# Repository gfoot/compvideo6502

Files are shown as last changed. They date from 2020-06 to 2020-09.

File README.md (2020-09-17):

# Composite/component video controller for homebrew 6502 computers

<table>
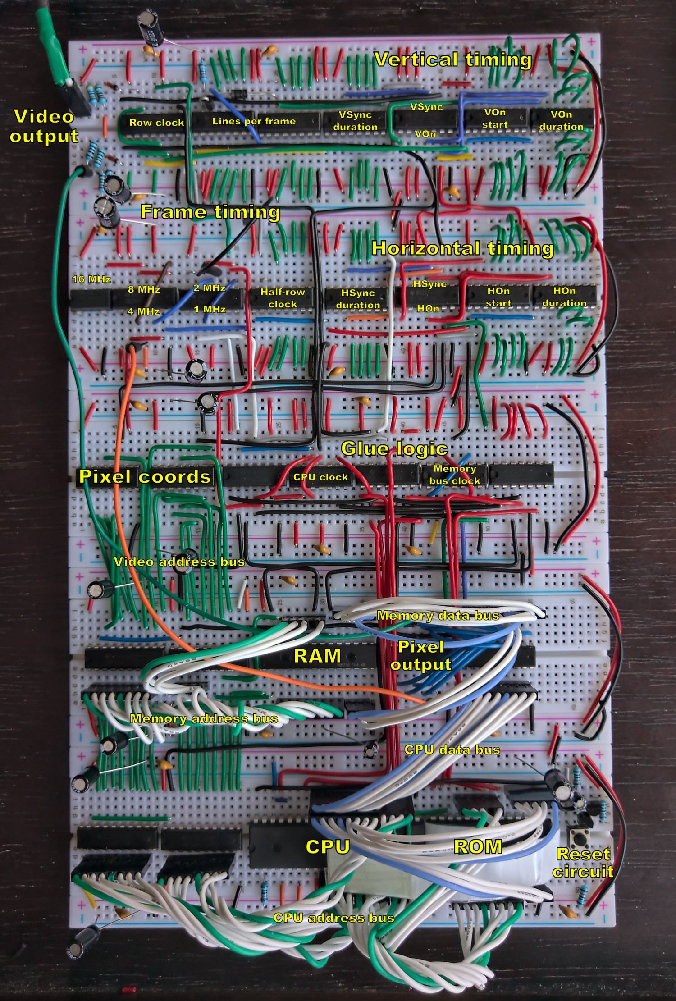
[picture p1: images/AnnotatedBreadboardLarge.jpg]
Annotated image of working build
  <tr><td rowspan="2"></td><td>Output image</td></tr>
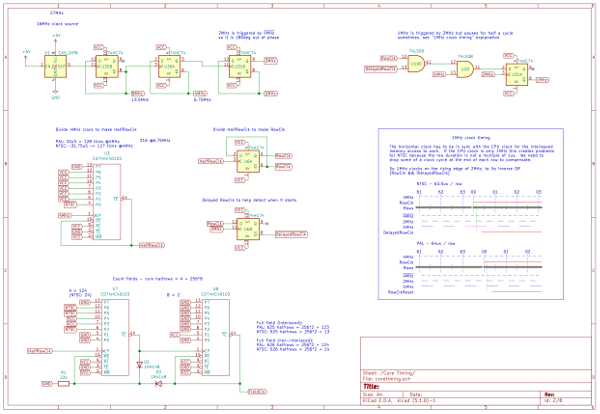
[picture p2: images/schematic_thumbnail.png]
Schematic (PDF)
  <tr><td></td></tr>
</table>

This is my second iteration video output circuit for homebrew 6502 computers.  It's designed to work in a way that's fairly close to
how early 80s microcomputers tended to work, which means RAM shared between CPU and video controller, as this tends to provide the
fastest possible access for the CPU to the video memory.

In this second iteration, the main change from V1 is that the timings are easily configurable, allowing it to support NTSC as well
as PAL with just a few jumper changes, as well as non-standard sync timings if you want to experiment; and the image placement and
size is also easily configurable.

You can also use interlacing to double the vertical resolution to 512 pixels, and if you swap the clock crystal and adjust some
other timings, you can double the horizontal resolution as well.

More involved, higher clock frequencies and maybe more counters would also allow HD resolutions such as 720p and 1080i, though I
haven't tried those yet, and VGA if you also change the output layer to output plain RGB.

The limiting factor at these higher resolutions becomes memory - 384x256x2 already uses nearly half of the RAM.  I'm considering
addressing this through a banking scheme in an upcoming V3.

# Project contents

This project contains:
* Full KiCad schematics for the new design (<a href="images/compvideo6502_schematic.pdf">also available in PDF format</a>)
* A "PCB" layout that represents how you could build this on an array of five breadboards

This includes the 6502, RAM, ROM, oscillator, reset circuit, and address decoding circuits, along 
with the video controller.  If you're already happy with the way you're doing those in an existing system then you could mostly 
keep your old design instead, but the RAM and clock need to be integrated here, in order to be shared with the video controller.

# Next steps and expansion ideas

There are a few things I plan to do next, and I'm not sure what the order will be.  Feedback/contributions welcome - let me know 
if you try these or have other ideas!

* Upload some OS code - I have the code from my previous iteration which should work pretty well
* Document and explain it, maybe make a step-by-step build-and-test guide, video tutorial, or something like that
* Make some games for it!  That was the whole point really, having a video output circuit that's fast enough to support 
the kinds of game I grew up playing
* Colour output - using component video, pretty simple to add
* Higher resolutions?  Doubling the horizontal resolution is possible with the right pixel frequency (13.5MHz instead
of 16MHz) - and doubling the vertical resolution also works fine through interlacing.  Component video can also go up to 1080i I 
think, but can't find good specs on the sync frequencies for that.
* VGA output?  It's fairly similar, just higher frequency - but may be possible by swapping the crystal and adjusting the timings.  
It's why I wanted to make this more configurable than my first one.
* Planar video memory, as used on EGA and VGA graphics cards on PCs - I've always found it an interesting architecture, and it 
seems like a good way to implement colour output without needing faster memory
* Software control over the timing registers would be very neat and not very hard to do

# Caveats

The output impedance isn't exactly what it's meant to be, but it's close enough I think.

The 16MHz base frequency is what the BBC Micro used back in the day, but I think in the digital age the standard pixel sampling 
frequency for SDTV is 13.5MHz.  As a result, on an LCD display you get blurring and moire effects at 8MHz; and at 16MHz you lose 
most of the pixel detail completely.  I think with a 13.5MHz base frequency the picture would be sharper overall.

My first iteration output correct pre- and post-vsync equalization pulses, and serrations during the vsync; I left that out this 
time around as it doesn't seem to be necessary these days.  Maybe I'm missing something though.  As far as I can tell chips like 
the 6845 never supported this anyway - at least it's not mentioned in the datasheets.  So I'm guessing that since at least the 
1980s nobody has bothered with them.

I haven't worked out interlacing yet.  Websites say that you can turn it off with the right combination of sync pulses, but my TV
always says it's interlaced, so either I'm doing it wrong, or the TV just never says "576p" anyway.  The design here is
intentionally fully-interlaced, which might lead to increased vertical resolution in the end.  It should be possible to uninterlace
it with a small change to the sync timings.  Actually I suspect that this is becase composite doesn't support progressive scan -
with component video the non-interlaced mode might work better.

I used a lot of 74HCT40103s in this design - they're incredibly useful, and were fundamental to the simplification and tweakability 
of the timings in this design.  However it seems they might be harder to find online than other chips I tend to use - I had to 
order a second batch, and it was harder to find them this time around.  So maybe it wasn't the best choice...  It's possible to use 
74HCT163s instead, but you'll need more of them as they're only 4-bit counters.

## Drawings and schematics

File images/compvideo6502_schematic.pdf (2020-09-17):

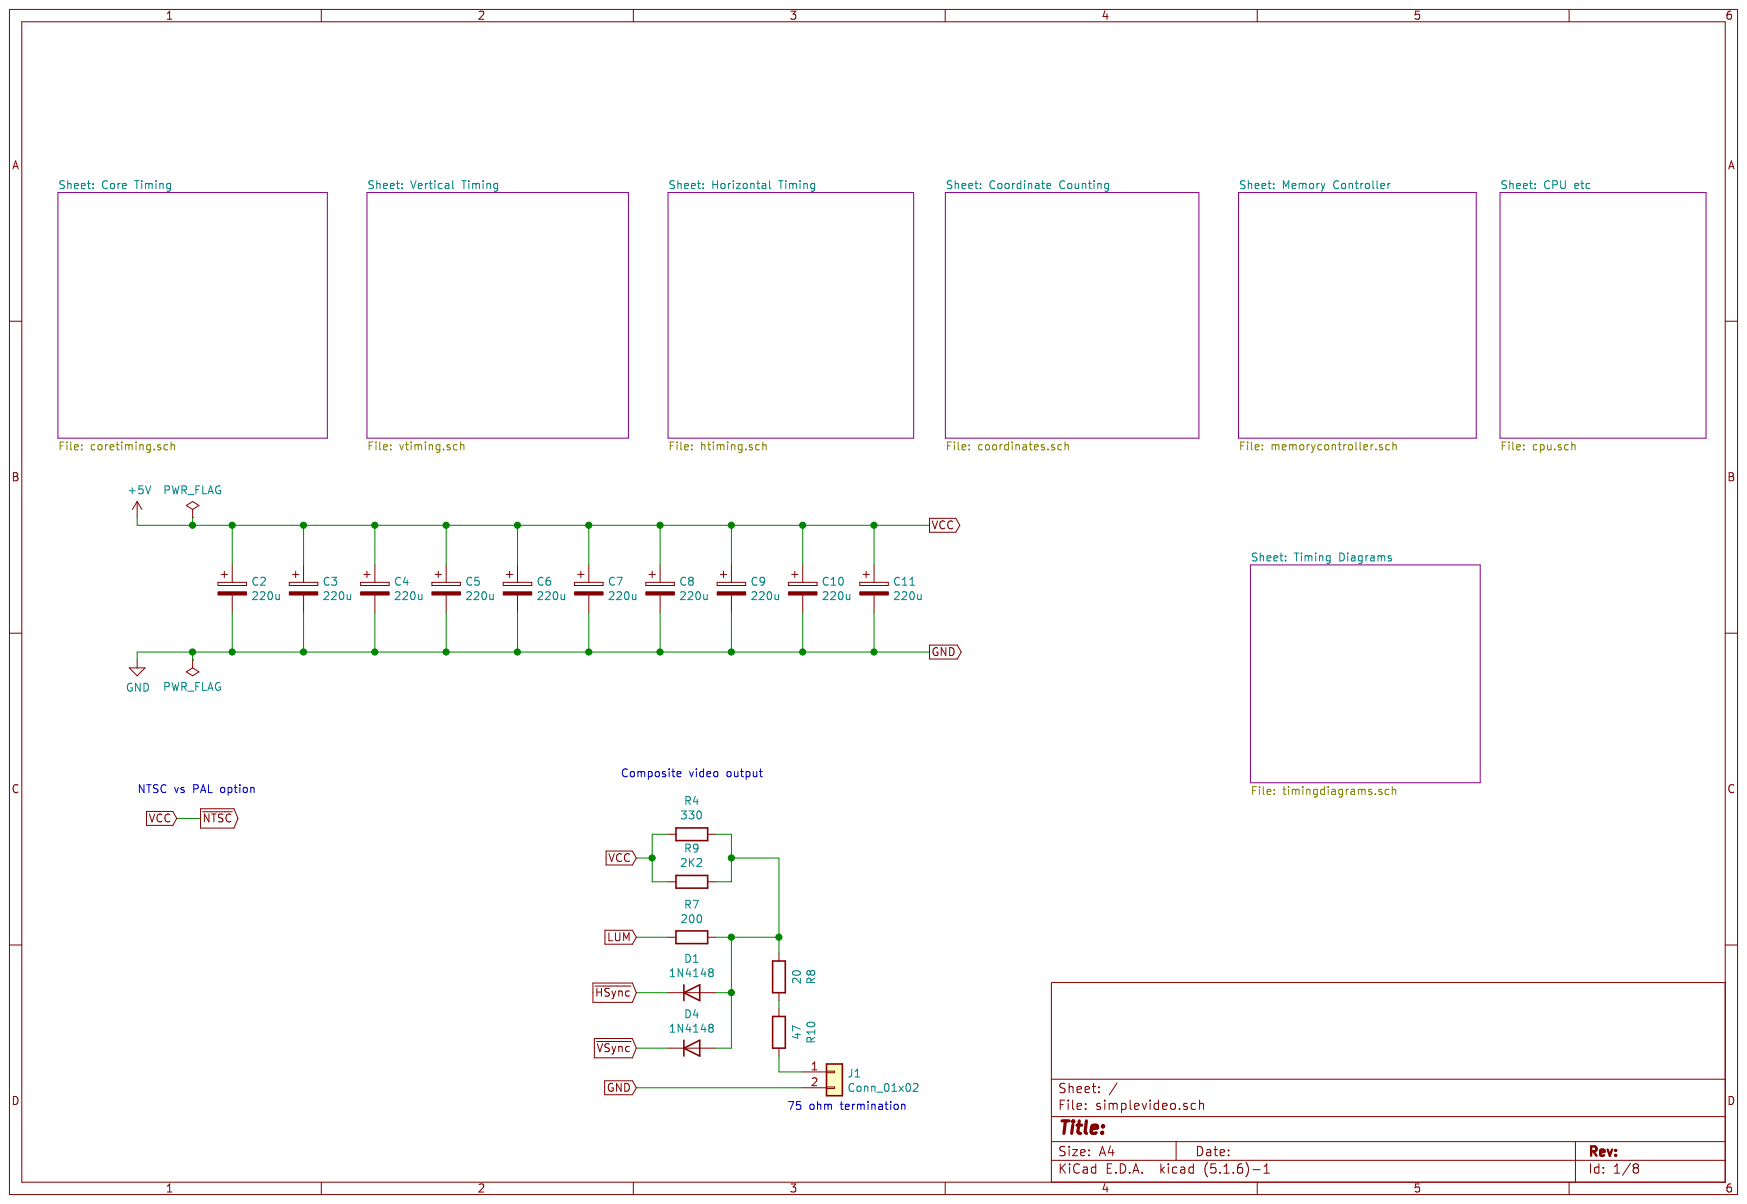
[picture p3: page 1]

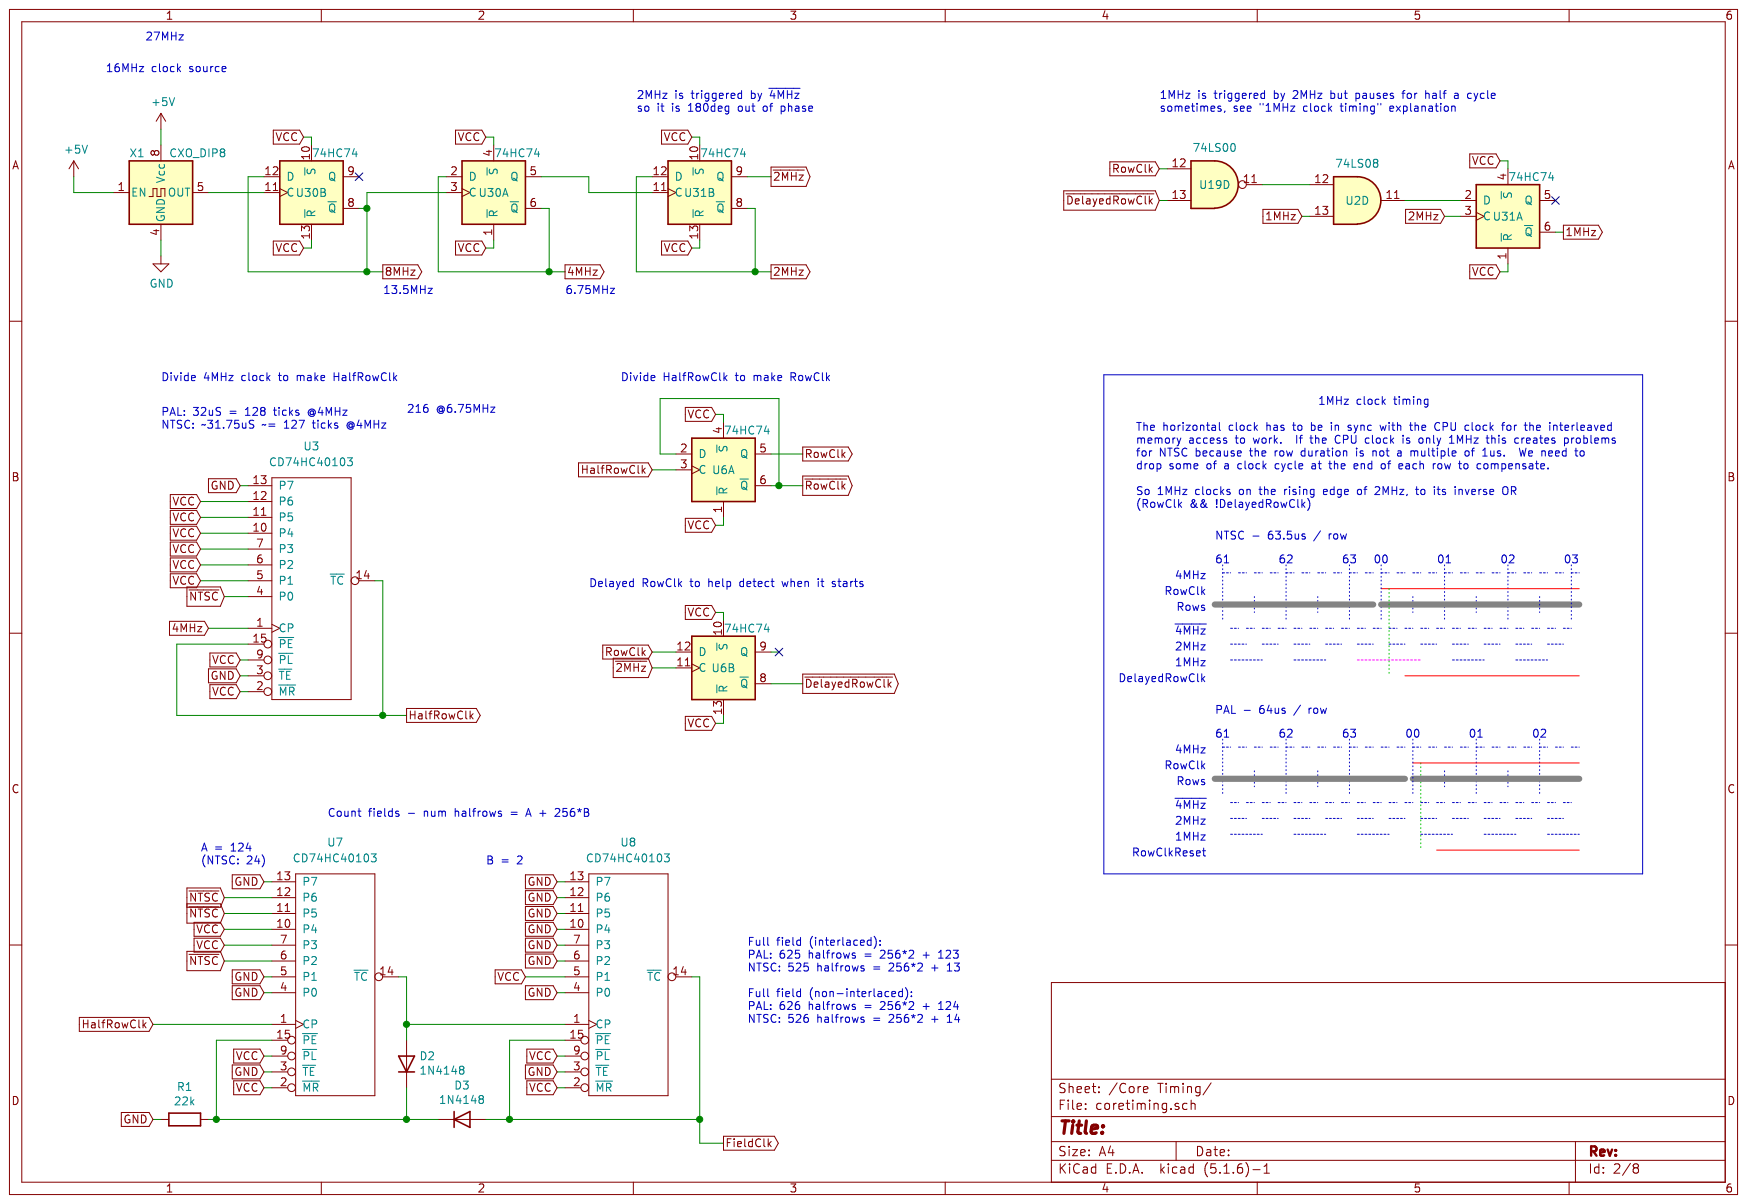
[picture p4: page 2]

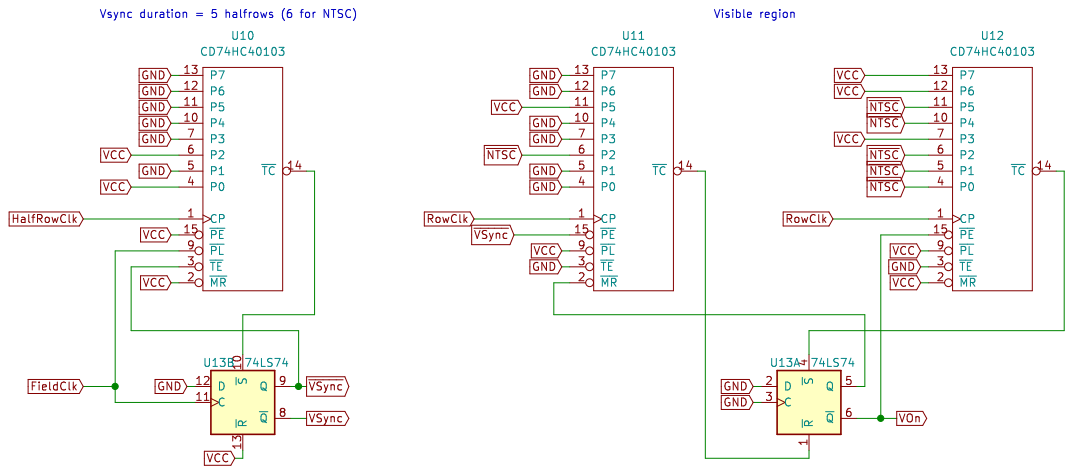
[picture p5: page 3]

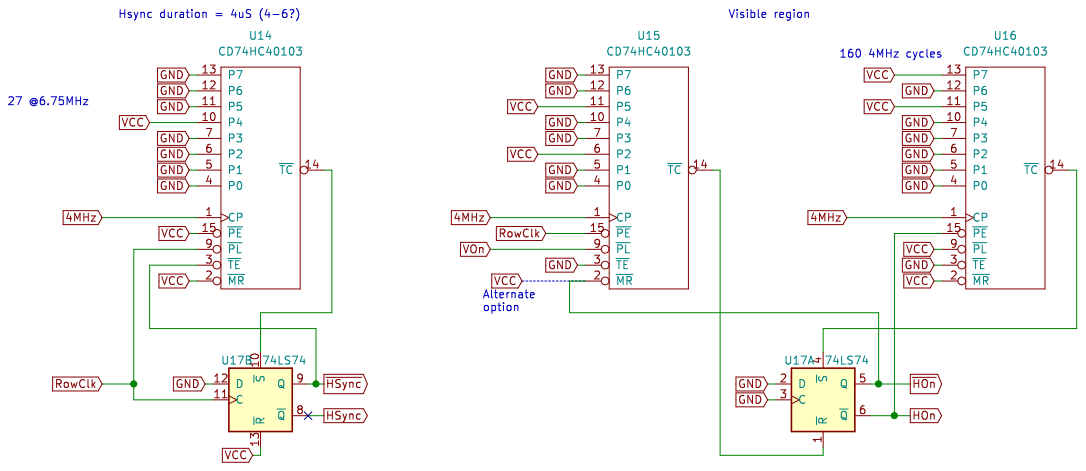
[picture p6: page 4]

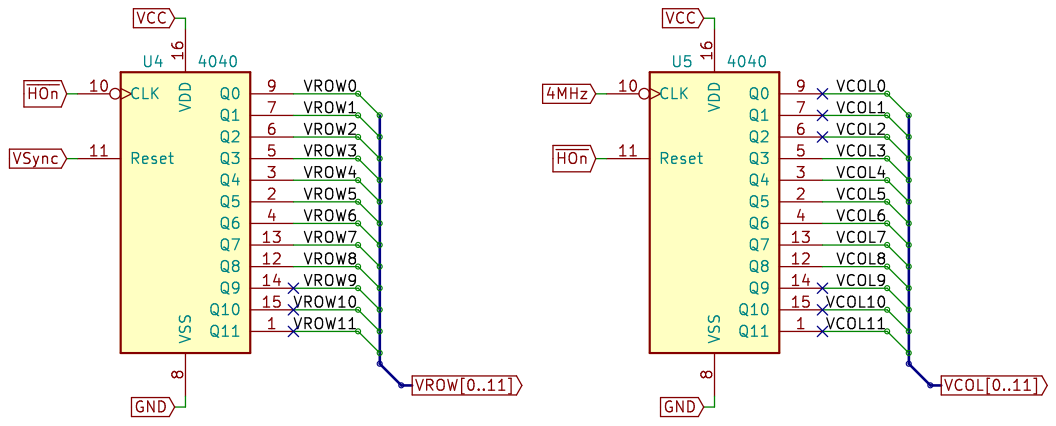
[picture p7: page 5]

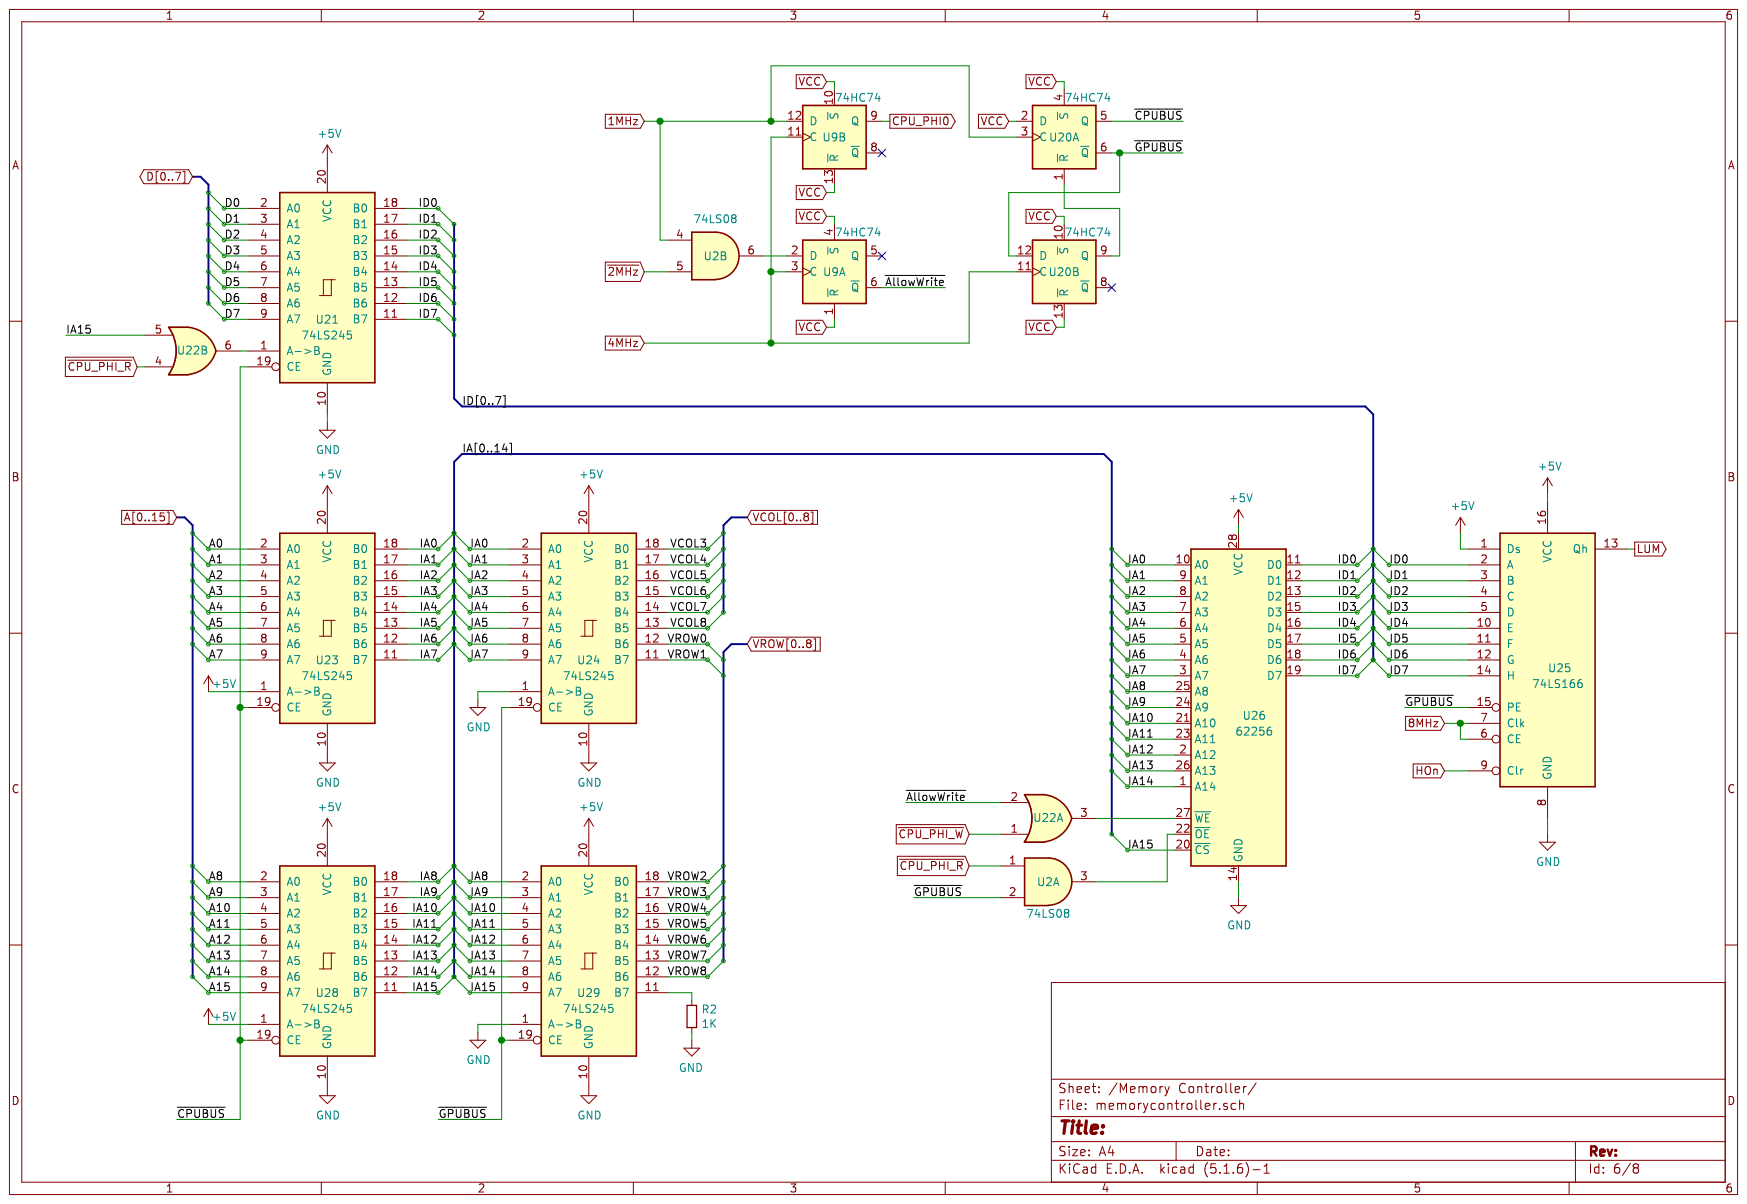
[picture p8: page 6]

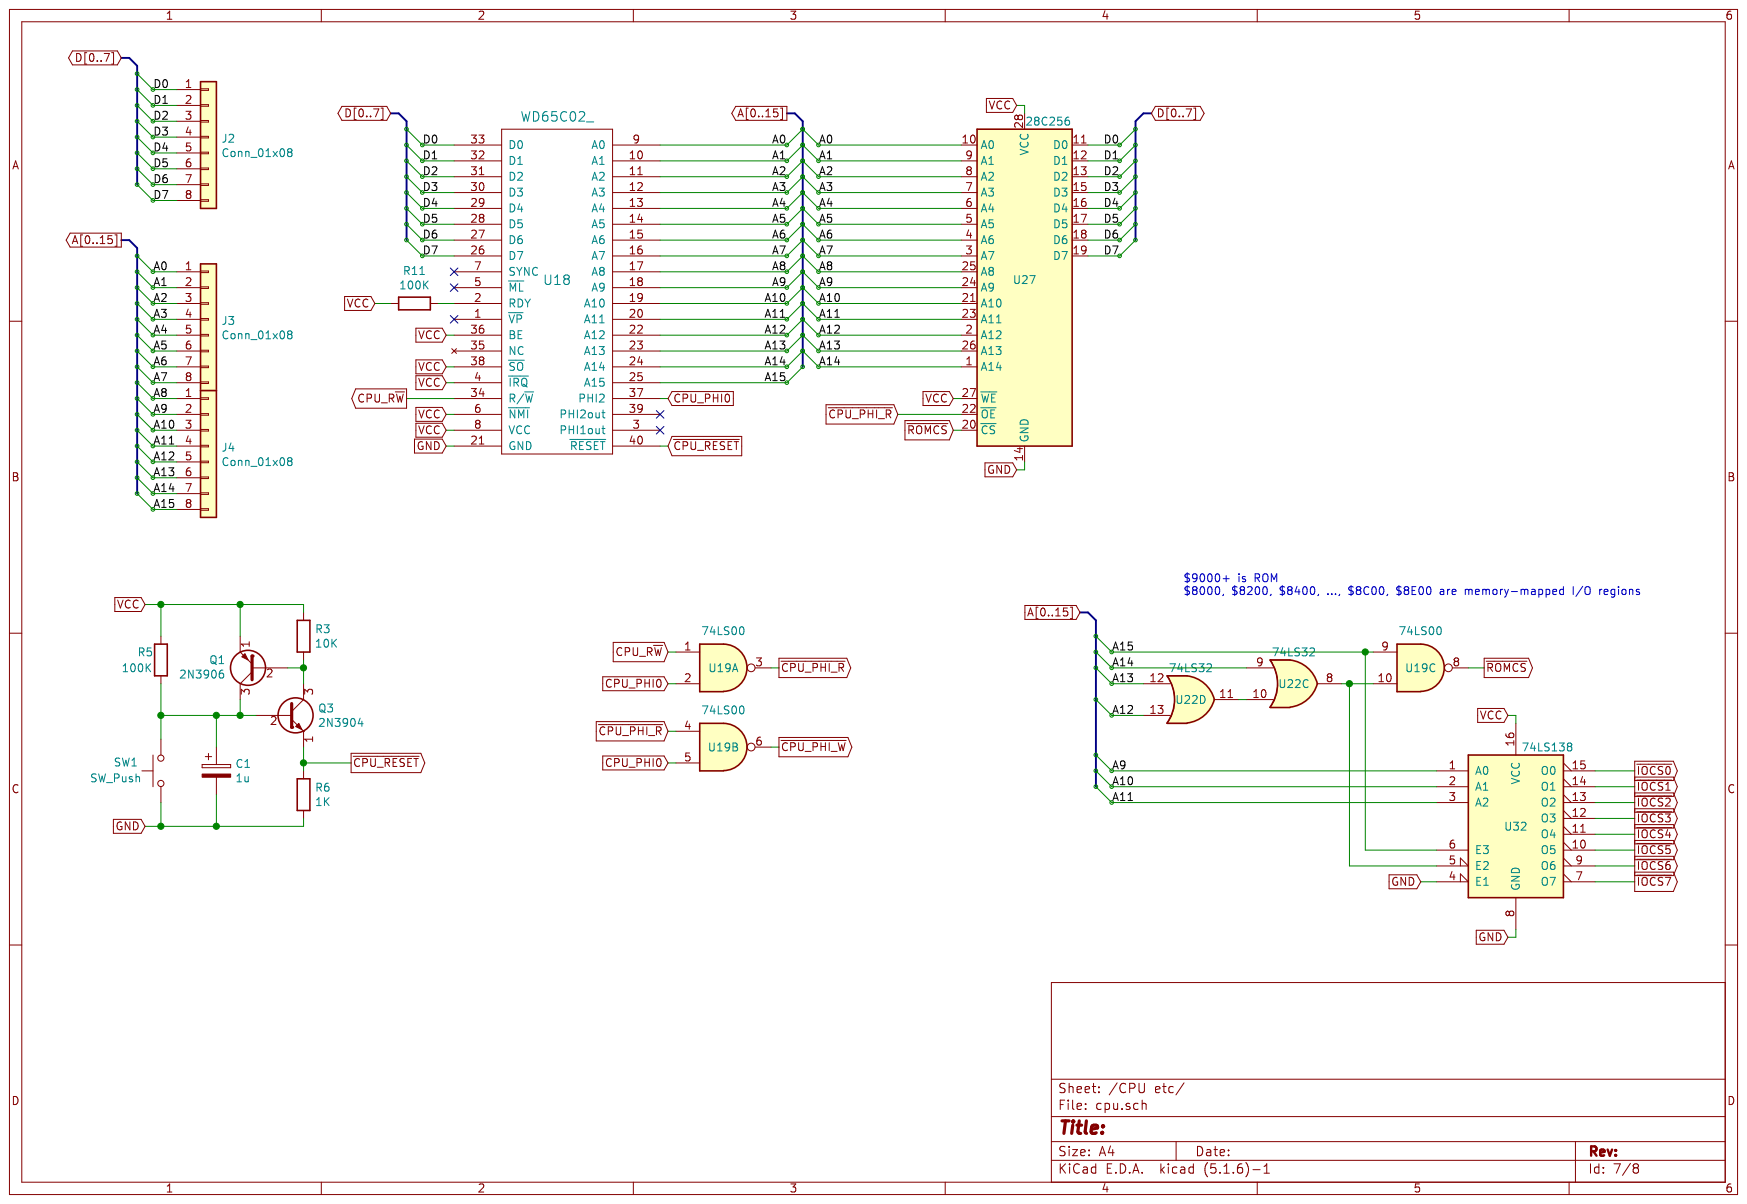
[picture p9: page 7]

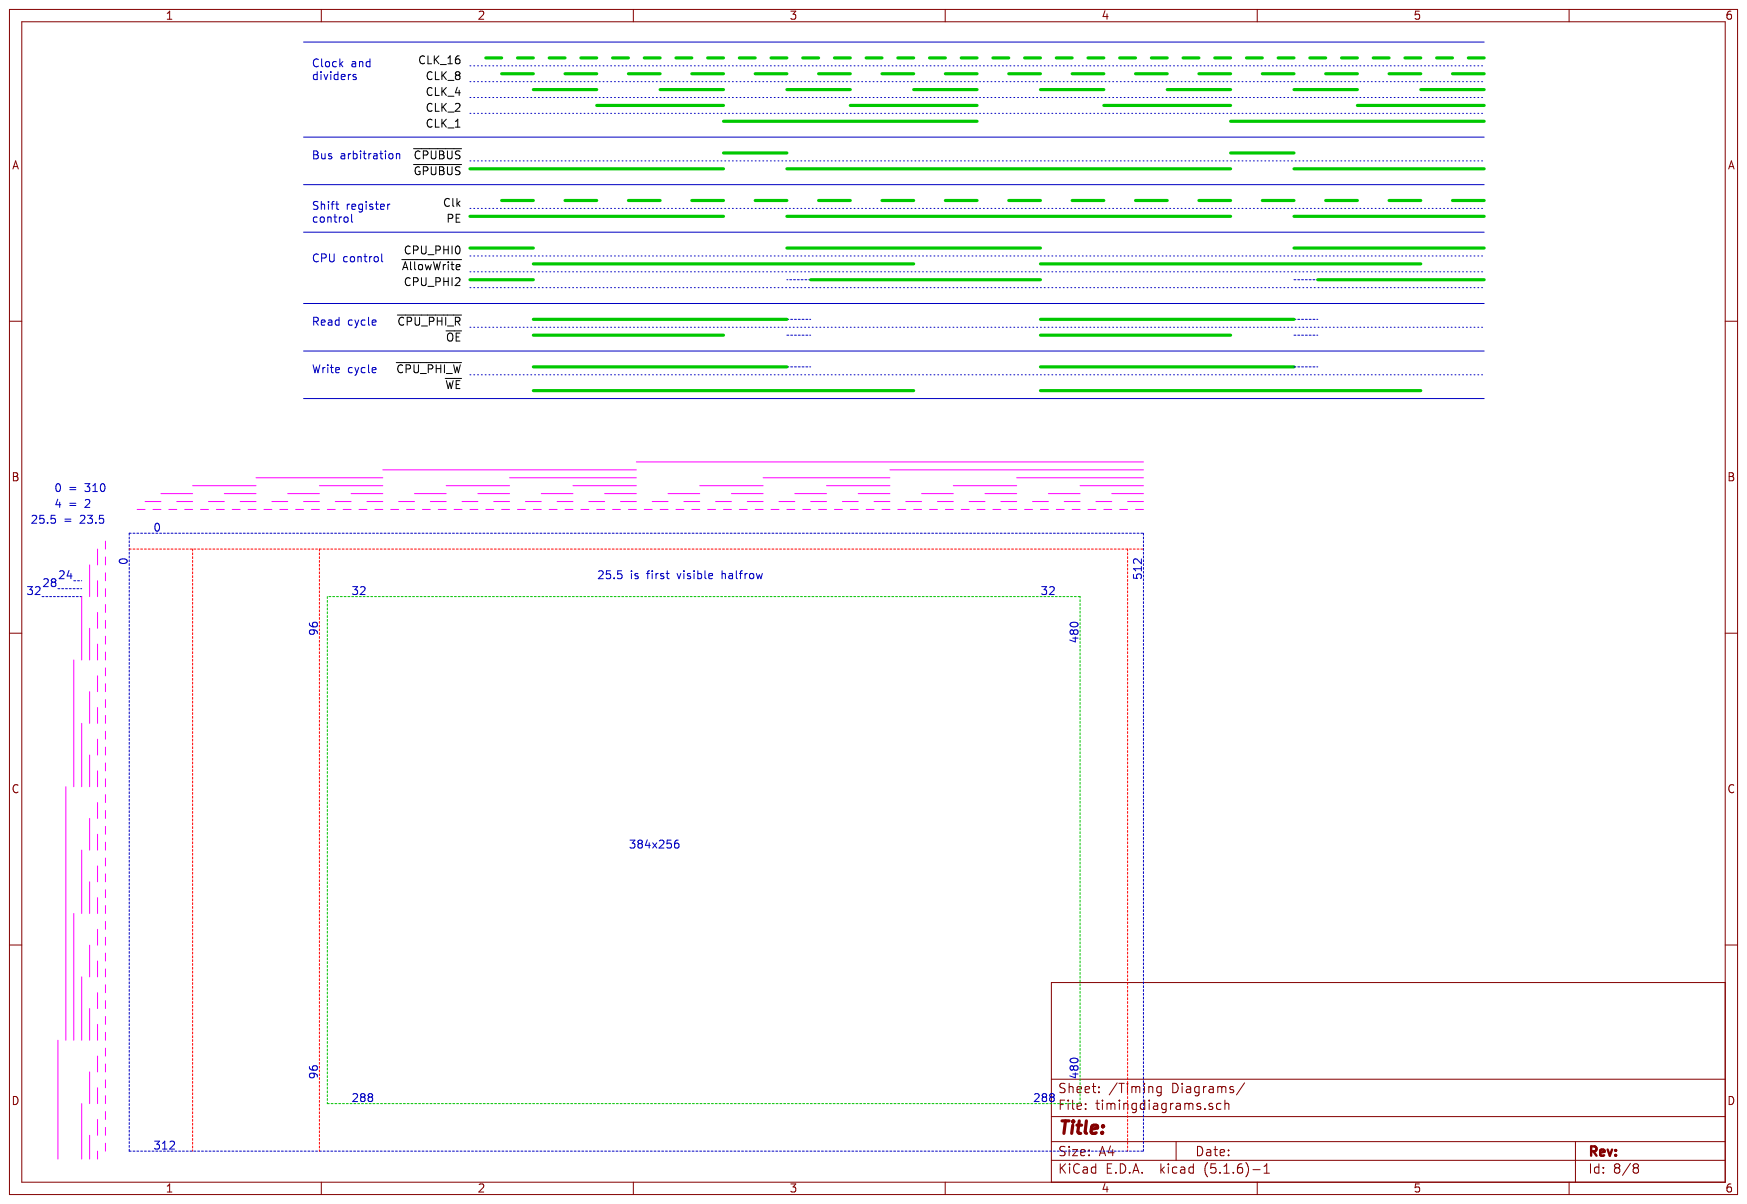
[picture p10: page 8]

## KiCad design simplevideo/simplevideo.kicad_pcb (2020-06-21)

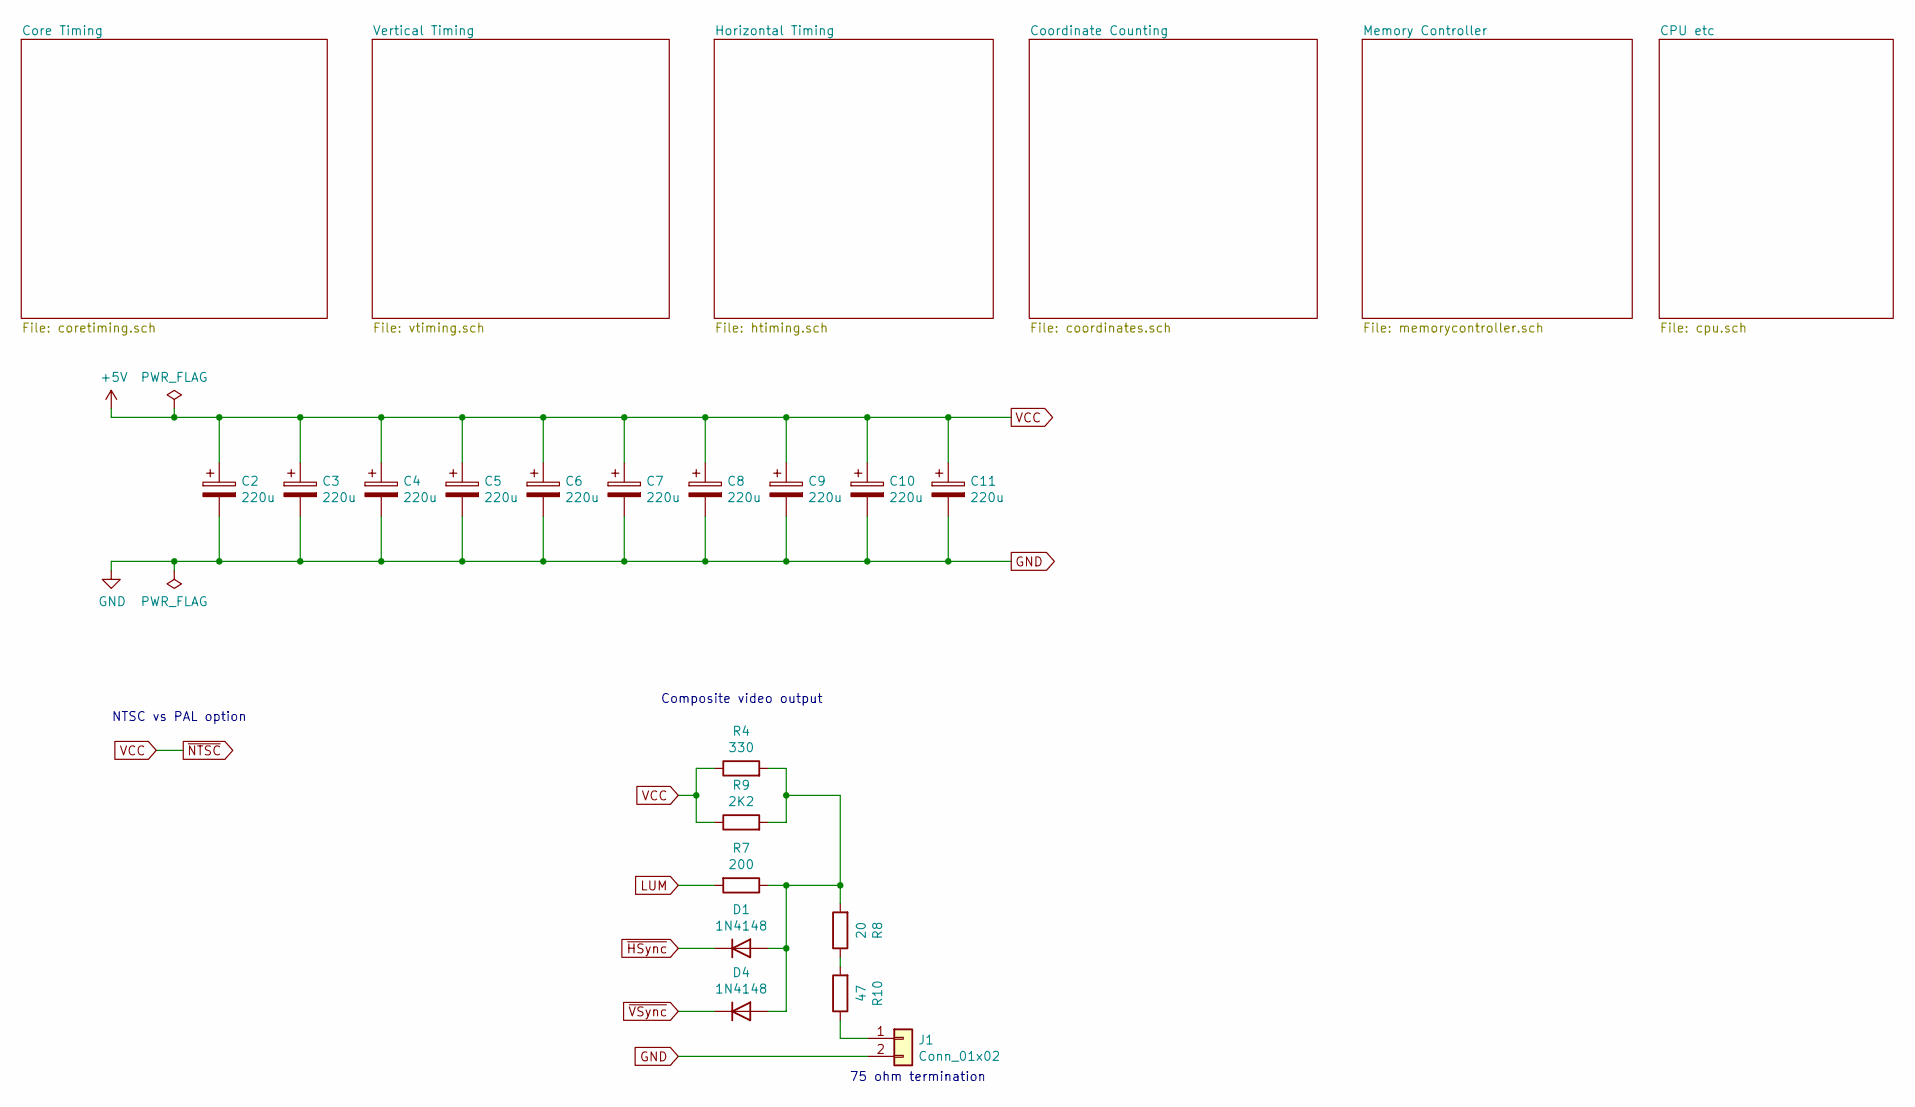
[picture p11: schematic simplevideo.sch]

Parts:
C2, C3, C4, C5, C6, C7, C8, C9, C10, C11: 220u; CP_Radial_D5.0mm_P2.50mm
D1, D4: 1N4148; D_DO-34_SOD68_P7.62mm_Horizontal
J1: Conn_01x02; PinHeader_1x02_P2.54mm_Vertical
R4: 330; R_Axial_DIN0204_L3.6mm_D1.6mm_P7.62mm_Horizontal
R7: 200; R_Axial_DIN0204_L3.6mm_D1.6mm_P7.62mm_Horizontal
R8: 20; R_Axial_DIN0204_L3.6mm_D1.6mm_P7.62mm_Horizontal
R9: 2K2; R_Axial_DIN0204_L3.6mm_D1.6mm_P7.62mm_Horizontal
R10: 47; R_Axial_DIN0204_L3.6mm_D1.6mm_P7.62mm_Horizontal

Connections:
GND: C2.2, C3.2, C4.2, C5.2, C6.2, C7.2, C8.2, C9.2, C10.2, C11.2, J1.2; also elsewhere on the board
LUM: R7.2; also elsewhere on the board
unnamed: D1.2 (A), D4.2 (A), R4.2, R7.1, R8.2, R9.2
unnamed: J1.1, R10.1
unnamed: R8.1, R10.2
VCC: C2.1, C3.1, C4.1, C5.1, C6.1, C7.1, C8.1, C9.1, C10.1, C11.1, R4.1, R9.1; also elsewhere on the board
~HSync: D1.1 (K); also elsewhere on the board
~VSync: D4.1 (K); also elsewhere on the board

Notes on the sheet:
NTSC vs PAL option
Composite video output
75 ohm termination

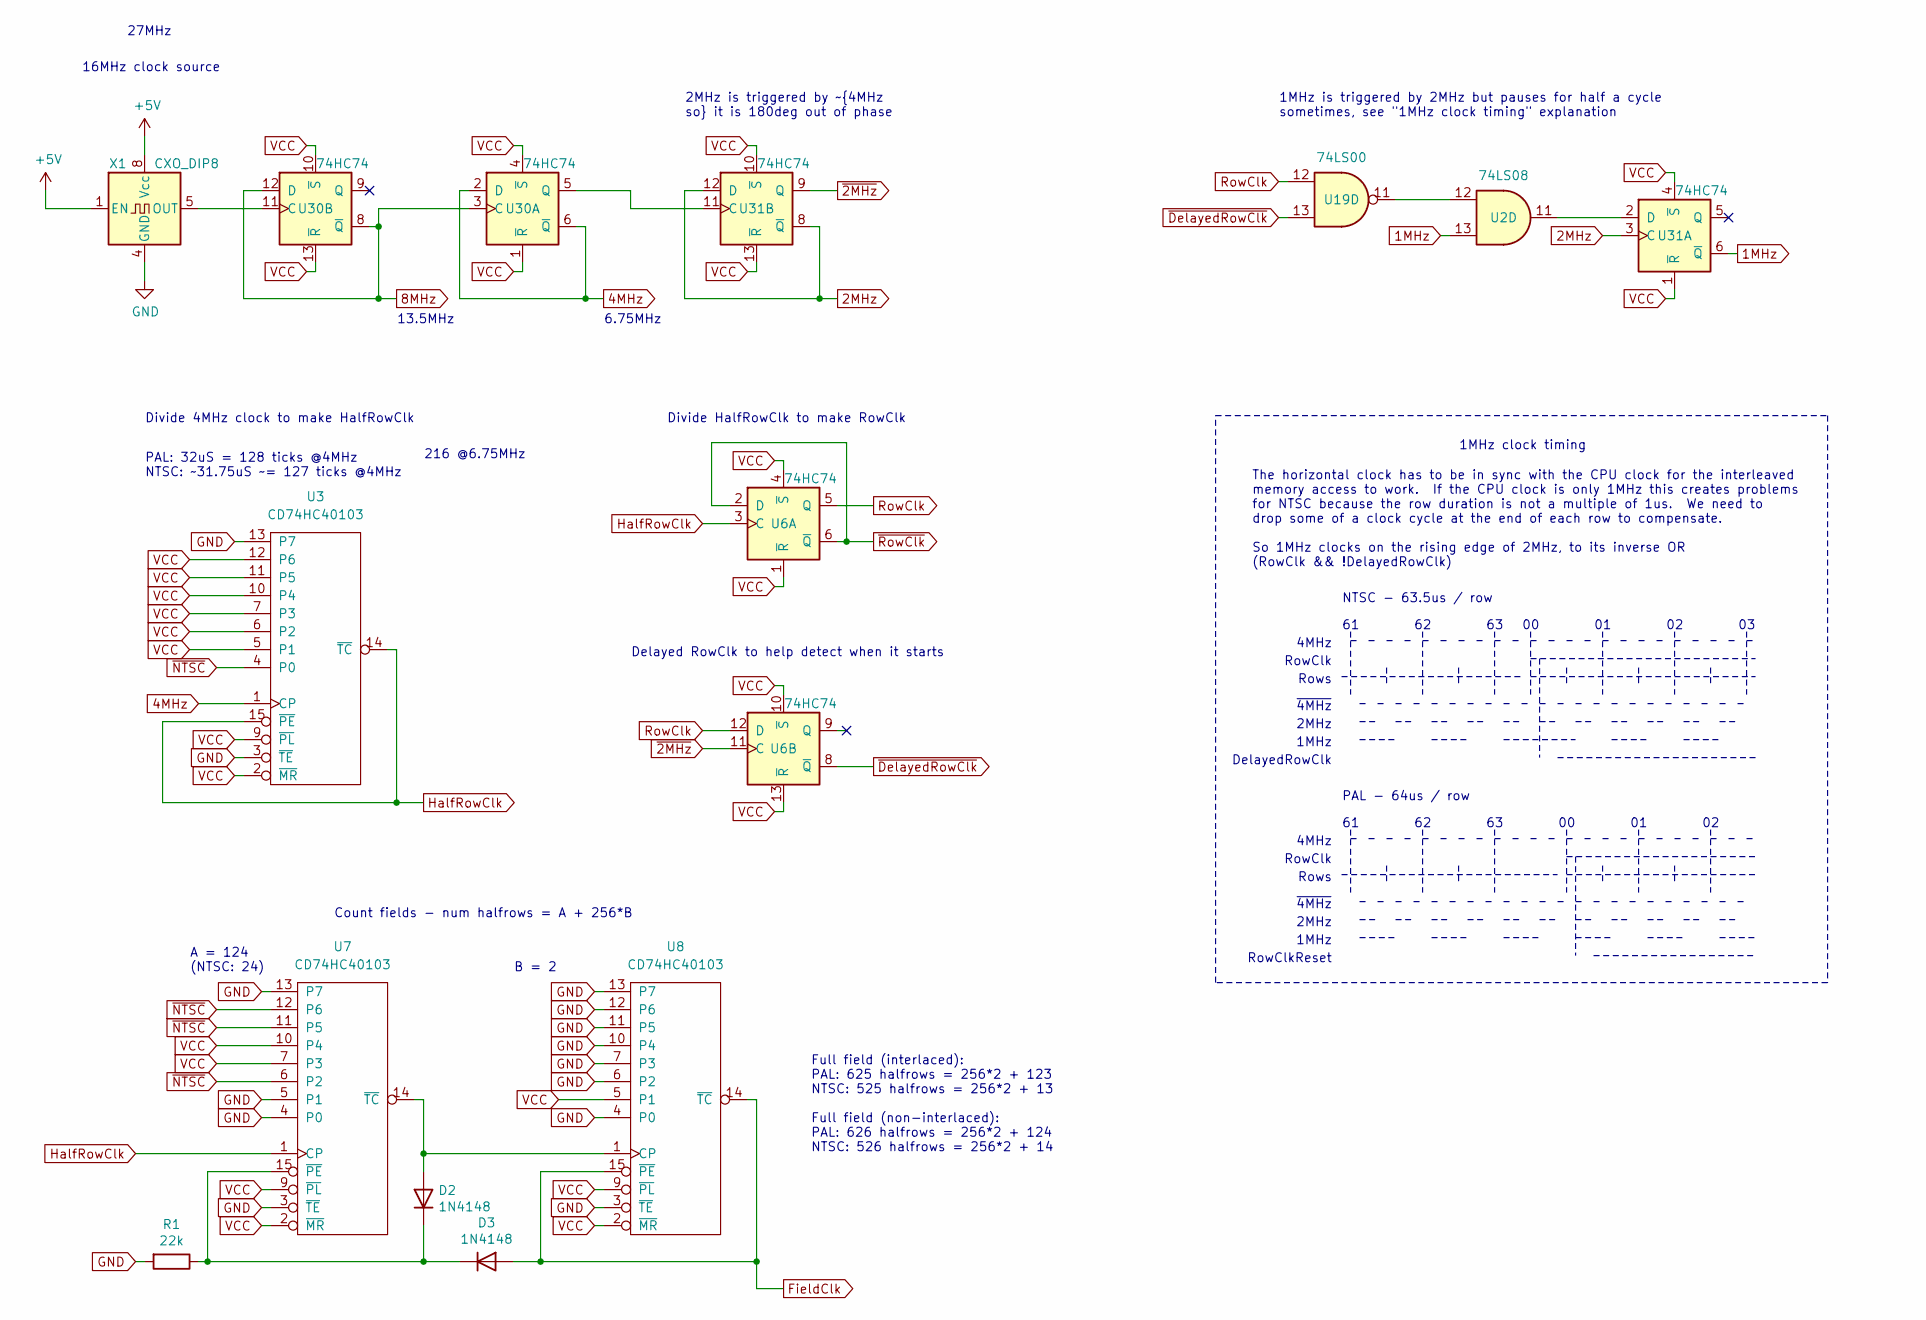
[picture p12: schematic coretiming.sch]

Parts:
D2, D3: 1N4148; D_DO-34_SOD68_P7.62mm_Horizontal
R1: 22k; R_Axial_DIN0204_L3.6mm_D1.6mm_P7.62mm_Horizontal
U2: 74LS08; DIP-14_W7.62mm
U3, U7, U8: CD74HC40103; DIP-16_W7.62mm
U6, U30, U31: 74HC74; DIP-14_W7.62mm
U19: 74LS00; DIP-14_W7.62mm
X1: CXO_DIP8; Oscillator_DIP-8

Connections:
1MHz: U2.13, U31.6 (~Q); also elsewhere on the board
2MHz: U31.3 (C), U31.8 (~Q), U31.12 (D)
4MHz: U3.1 (CP), U30.2 (D), U30.6 (~Q); also elsewhere on the board
8MHz: U30.3 (C), U30.8 (~Q), U30.12 (D); also elsewhere on the board
FieldClk: D3.2 (A), U8.14 (~TC), U8.15 (~PE); also elsewhere on the board
GND: R1.2, U3.3 (~TE), U3.8 (GND), U3.13 (P7), U7.3 (~TE), U7.4 (P0), U7.5 (P1), U7.8 (GND), U7.13 (P7), U8.3 (~TE), U8.4 (P0), U8.6 (P2), U8.7 (P3), U8.8 (GND), U8.10 (P4), U8.11 (P5), U8.12 (P6), U8.13 (P7), X1.4 (GND); also elsewhere on the board
HalfRowClk: U3.14 (~TC), U3.15 (~PE), U6.3 (C), U7.1 (CP); also elsewhere on the board
unnamed: D2.1 (K), D3.1 (K), R1.1, U7.15 (~PE)
unnamed: D2.2 (A), U7.14 (~TC), U8.1 (CP)
unnamed: U2.11, U31.2 (D)
unnamed: U2.12, U19.11
unnamed: U30.5 (Q), U31.11 (C)
unnamed: U30.11 (C), X1.5 (OUT)
RowClk: U6.5 (Q), U6.12 (D), U19.12; also elsewhere on the board
VCC: U3.2 (~MR), U3.4 (P0), U3.5 (P1), U3.6 (P2), U3.7 (P3), U3.9 (~PL), U3.10 (P4), U3.11 (P5), U3.12 (P6), U3.16 (VCC), U6.1 (~R), U6.4 (~S), U6.10 (~S), U6.13 (~R), U7.2 (~MR), U7.6 (P2), U7.7 (P3), U7.9 (~PL), U7.10 (P4), U7.11 (P5), U7.12 (P6), U7.16 (VCC), U8.2 (~MR), U8.5 (P1), U8.9 (~PL), U8.16 (VCC), U30.1 (~R), U30.4 (~S), U30.10 (~S), U30.13 (~R), U31.1 (~R), U31.4 (~S), U31.10 (~S), U31.13 (~R), X1.1 (EN), X1.8 (Vcc); also elsewhere on the board
~2MHz: U6.11 (C), U31.9 (Q); also elsewhere on the board
~DelayedRowClk: U6.8 (~Q), U19.13
~RowClk: U6.2 (D), U6.6 (~Q)

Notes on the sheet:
PAL: 32uS = 128 ticks @4MHz NTSC: ~~31.75uS ~~= 127 ticks @4MHz
Divide 4MHz clock to make HalfRowClk
Divide HalfRowClk to make RowClk
Full field (interlaced): PAL: 625 halfrows = 256*2 + 123 NTSC: 525 halfrows = 256*2 + 13 Full field (non-interlaced): PAL: 626 halfrows = 256*2 + 124 NTSC: 526 halfrows = 256*2 + 14
16MHz clock source
Count fields - num halfrows = A + 256*B
A = 124 (NTSC: 24)
B = 2
The horizontal clock has to be in sync with the CPU clock for the interleaved memory access to work. If the CPU clock is only 1MHz this creates problems for NTSC because the row duration is not a multiple of 1us. We need to drop some of a clock cycle at the end of each row to compensate. So 1MHz cl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
1MHz
2MHz
~4MHz
Rows
RowClk
4MHz
RowClkReset
NTSC - 63.5us / row
PAL - 64us / row
DelayedRowClk
1MHz clock timing
2MHz is triggered by ~4MHz so it is 180deg out of phase
1MHz is triggered by 2MHz but pauses for half a cycle sometimes, see "1MHz clock timing" explanation
Delayed RowClk to help detect when it starts
27MHz
13.5MHz
6.75MHz
216 @6.75MHz

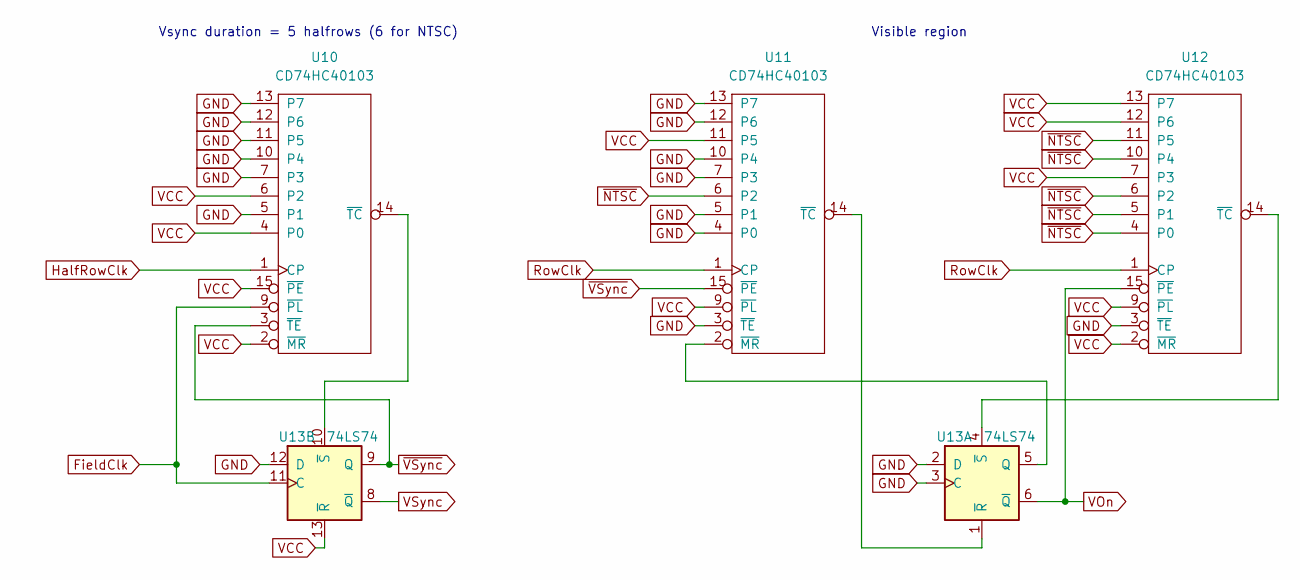
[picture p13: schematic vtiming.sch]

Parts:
U10, U11, U12: CD74HC40103; DIP-16_W7.62mm
U13: 74LS74; DIP-14_W7.62mm

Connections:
FieldClk: U10.9 (~PL), U13.11 (C); also elsewhere on the board
GND: U10.5 (P1), U10.7 (P3), U10.8 (GND), U10.10 (P4), U10.11 (P5), U10.12 (P6), U10.13 (P7), U11.3 (~TE), U11.4 (P0), U11.5 (P1), U11.7 (P3), U11.8 (GND), U11.10 (P4), U11.12 (P6), U11.13 (P7), U12.3 (~TE), U12.8 (GND), U13.2 (D), U13.3 (C), U13.12 (D); also elsewhere on the board
HalfRowClk: U10.1 (CP); also elsewhere on the board
unnamed: U10.14 (~TC), U13.10 (~S)
unnamed: U11.2 (~MR), U13.5 (Q)
unnamed: U11.14 (~TC), U13.1 (~R)
unnamed: U12.14 (~TC), U13.4 (~S)
RowClk: U11.1 (CP), U12.1 (CP); also elsewhere on the board
VCC: U10.2 (~MR), U10.4 (P0), U10.6 (P2), U10.15 (~PE), U10.16 (VCC), U11.6 (P2), U11.9 (~PL), U11.11 (P5), U11.16 (VCC), U12.2 (~MR), U12.4 (P0), U12.5 (P1), U12.6 (P2), U12.7 (P3), U12.9 (~PL), U12.10 (P4), U12.11 (P5), U12.12 (P6), U12.13 (P7), U12.16 (VCC), U13.13 (~R); also elsewhere on the board
VOn: U12.15 (~PE), U13.6 (~Q); also elsewhere on the board
VSync: U13.8 (~Q); also elsewhere on the board
~VSync: U10.3 (~TE), U11.15 (~PE), U13.9 (Q); also elsewhere on the board

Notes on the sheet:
Vsync duration = 5 halfrows (6 for NTSC)
Visible region

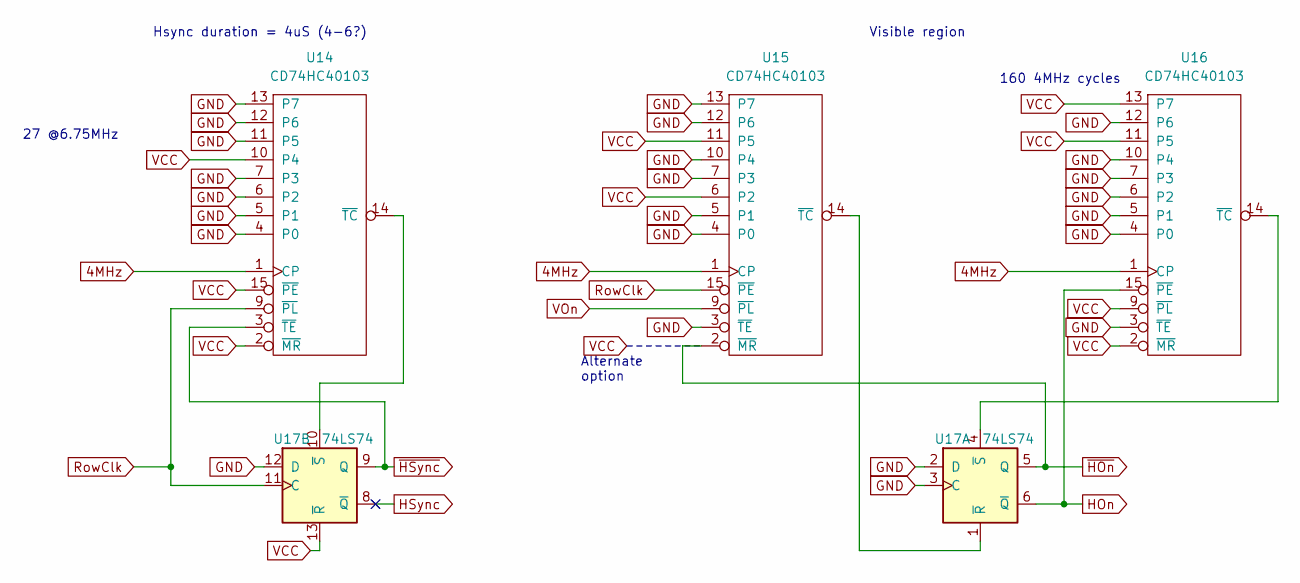
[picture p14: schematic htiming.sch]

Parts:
U14, U15, U16: CD74HC40103; DIP-16_W7.62mm
U17: 74LS74; DIP-14_W7.62mm

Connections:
4MHz: U14.1 (CP), U15.1 (CP), U16.1 (CP); also elsewhere on the board
GND: U14.4 (P0), U14.5 (P1), U14.6 (P2), U14.7 (P3), U14.8 (GND), U14.11 (P5), U14.12 (P6), U14.13 (P7), U15.3 (~TE), U15.4 (P0), U15.5 (P1), U15.7 (P3), U15.8 (GND), U15.10 (P4), U15.12 (P6), U15.13 (P7), U16.3 (~TE), U16.4 (P0), U16.5 (P1), U16.6 (P2), U16.7 (P3), U16.8 (GND), U16.10 (P4), U16.12 (P6), U17.2 (D), U17.3 (C), U17.12 (D); also elsewhere on the board
HOn: U16.15 (~PE), U17.6 (~Q); also elsewhere on the board
HSync: U17.8 (~Q)
unnamed: U14.14 (~TC), U17.10 (~S)
unnamed: U15.14 (~TC), U17.1 (~R)
unnamed: U16.14 (~TC), U17.4 (~S)
RowClk: U14.9 (~PL), U15.15 (~PE), U17.11 (C); also elsewhere on the board
VCC: U14.2 (~MR), U14.10 (P4), U14.15 (~PE), U14.16 (VCC), U15.6 (P2), U15.11 (P5), U15.16 (VCC), U16.2 (~MR), U16.9 (~PL), U16.11 (P5), U16.13 (P7), U16.16 (VCC), U17.13 (~R); also elsewhere on the board
VOn: U15.9 (~PL); also elsewhere on the board
~HOn: U15.2 (~MR), U17.5 (Q); also elsewhere on the board
~HSync: U14.3 (~TE), U17.9 (Q); also elsewhere on the board

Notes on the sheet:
Hsync duration = 4uS (4-6?)
Visible region
Alternate option
27 @6.75MHz
160 4MHz cycles

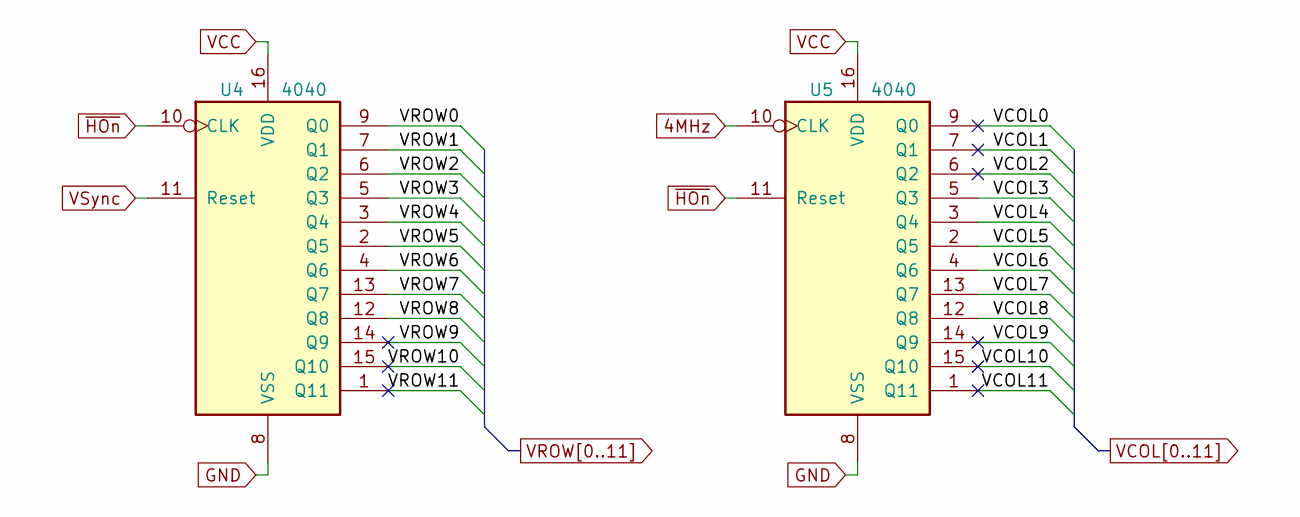
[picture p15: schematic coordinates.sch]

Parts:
U4, U5: 4040; DIP-16_W7.62mm

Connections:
4MHz: U5.10 (CLK); also elsewhere on the board
GND: U4.8 (VSS), U5.8 (VSS); also elsewhere on the board
VCC: U4.16 (VDD), U5.16 (VDD); also elsewhere on the board
VCOL0: U5.9 (Q0)
VCOL1: U5.7 (Q1)
VCOL2: U5.6 (Q2)
VCOL3: U5.5 (Q3); also elsewhere on the board
VCOL4: U5.3 (Q4); also elsewhere on the board
VCOL5: U5.2 (Q5); also elsewhere on the board
VCOL6: U5.4 (Q6); also elsewhere on the board
VCOL7: U5.13 (Q7); also elsewhere on the board
VCOL8: U5.12 (Q8); also elsewhere on the board
VCOL9: U5.14 (Q9)
VCOL10: U5.15 (Q10)
VCOL11: U5.1 (Q11)
VROW0: U4.9 (Q0); also elsewhere on the board
VROW1: U4.7 (Q1); also elsewhere on the board
VROW2: U4.6 (Q2); also elsewhere on the board
VROW3: U4.5 (Q3); also elsewhere on the board
VROW4: U4.3 (Q4); also elsewhere on the board
VROW5: U4.2 (Q5); also elsewhere on the board
VROW6: U4.4 (Q6); also elsewhere on the board
VROW7: U4.13 (Q7); also elsewhere on the board
VROW8: U4.12 (Q8); also elsewhere on the board
VROW9: U4.14 (Q9)
VROW10: U4.15 (Q10)
VROW11: U4.1 (Q11)
VSync: U4.11 (Reset); also elsewhere on the board
~HOn: U4.10 (CLK), U5.11 (Reset); also elsewhere on the board

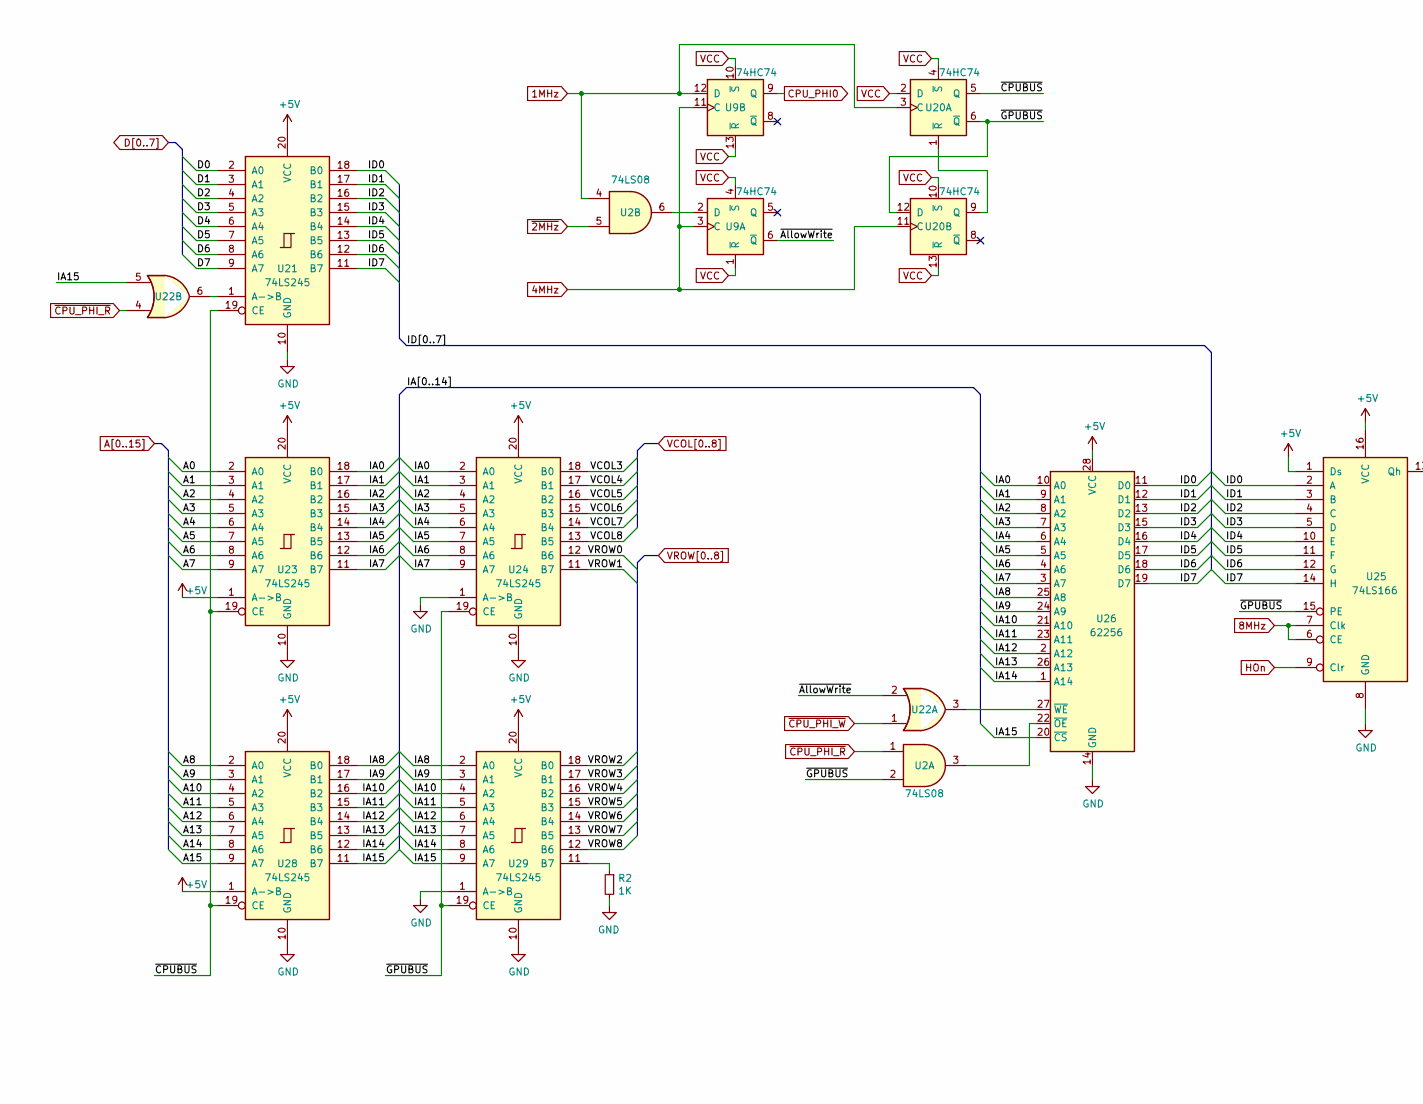
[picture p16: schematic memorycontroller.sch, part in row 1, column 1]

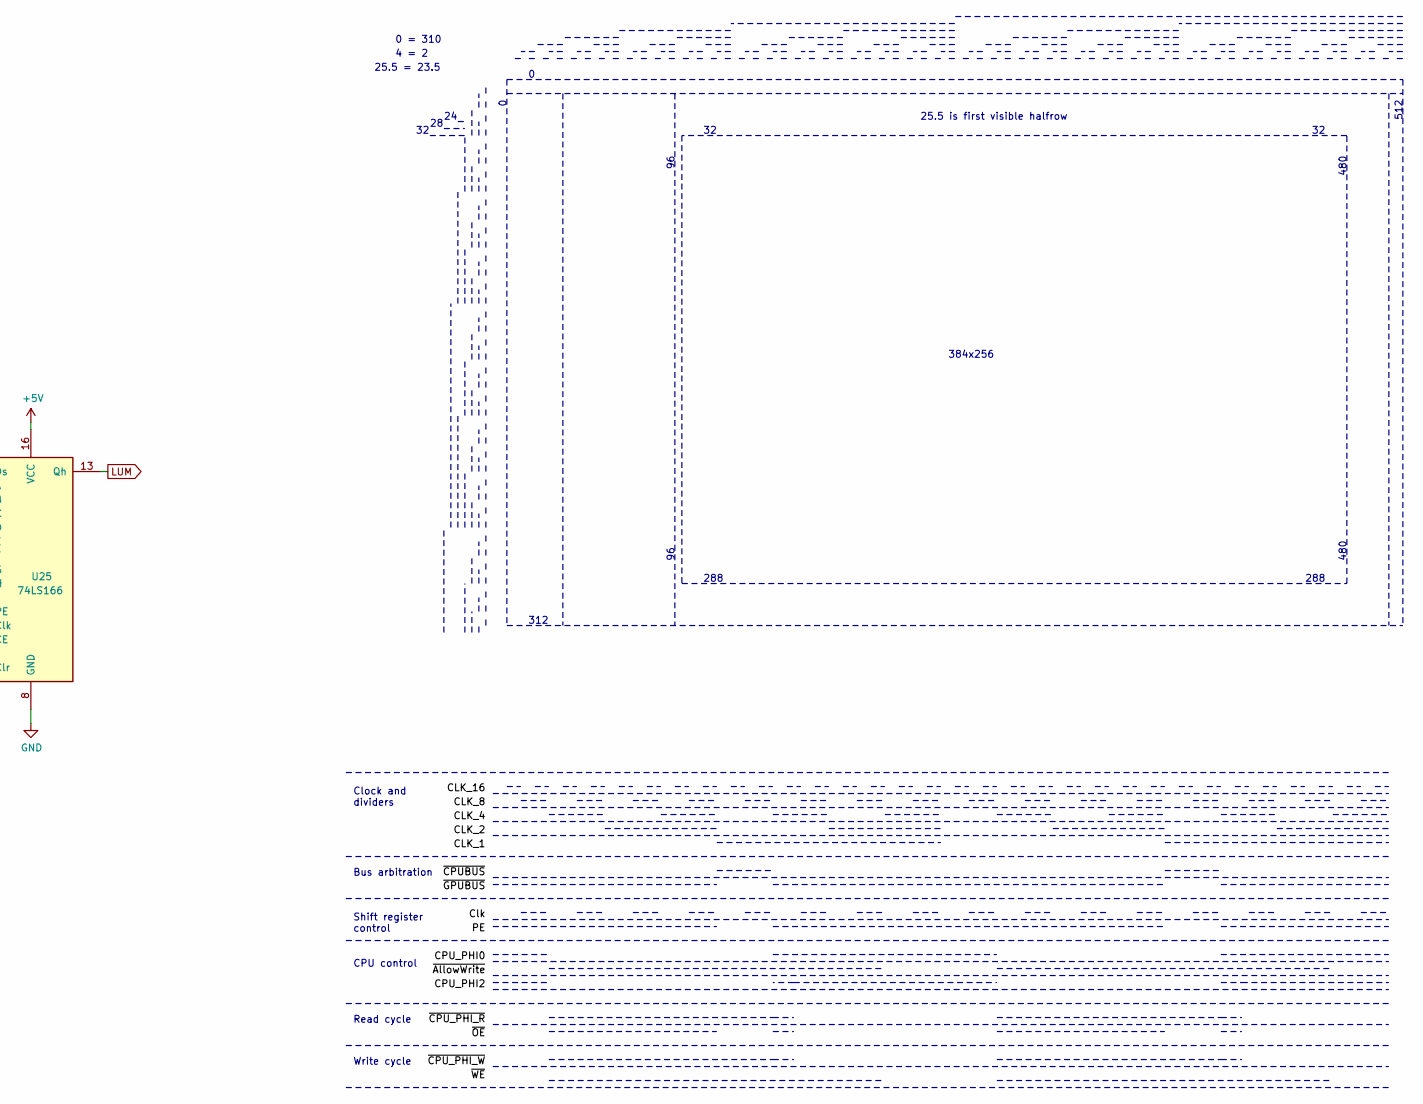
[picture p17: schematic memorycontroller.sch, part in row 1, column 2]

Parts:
R2: 1K; R_Axial_DIN0207_L6.3mm_D2.5mm_P7.62mm_Horizontal
U2: 74LS08; DIP-14_W7.62mm
U9, U20: 74HC74; DIP-14_W7.62mm
U21, U23, U24, U28, U29: 74LS245; DIP-20_W7.62mm
U22: 74LS32; DIP-14_W7.62mm
U25: 74LS166; DIP-16_W7.62mm
U26: 62256; DIP-28_W15.24mm

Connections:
1MHz: U2.4, U9.12 (D), U20.3 (C); also elsewhere on the board
4MHz: U9.3 (C), U9.11 (C), U20.11 (C); also elsewhere on the board
8MHz: U25.6 (CE), U25.7 (Clk); also elsewhere on the board
/Memory Controller/IA0: U23.18 (B0), U24.2 (A0), U26.10 (A0)
/Memory Controller/IA1: U23.17 (B1), U24.3 (A1), U26.9 (A1)
/Memory Controller/IA2: U23.16 (B2), U24.4 (A2), U26.8 (A2)
/Memory Controller/IA3: U23.15 (B3), U24.5 (A3), U26.7 (A3)
/Memory Controller/IA4: U23.14 (B4), U24.6 (A4), U26.6 (A4)
/Memory Controller/IA5: U23.13 (B5), U24.7 (A5), U26.5 (A5)
/Memory Controller/IA6: U23.12 (B6), U24.8 (A6), U26.4 (A6)
/Memory Controller/IA7: U23.11 (B7), U24.9 (A7), U26.3 (A7)
/Memory Controller/IA8: U26.25 (A8), U28.18 (B0), U29.2 (A0)
/Memory Controller/IA9: U26.24 (A9), U28.17 (B1), U29.3 (A1)
/Memory Controller/IA10: U26.21 (A10), U28.16 (B2), U29.4 (A2)
/Memory Controller/IA11: U26.23 (A11), U28.15 (B3), U29.5 (A3)
/Memory Controller/IA12: U26.2 (A12), U28.14 (B4), U29.6 (A4)
/Memory Controller/IA13: U26.26 (A13), U28.13 (B5), U29.7 (A5)
/Memory Controller/IA14: U26.1 (A14), U28.12 (B6), U29.8 (A6)
/Memory Controller/IA15: U22.5, U26.20 (~CS), U28.11 (B7), U29.9 (A7)
/Memory Controller/ID0: U21.18 (B0), U25.2 (A), U26.11 (D0)
/Memory Controller/ID1: U21.17 (B1), U25.3 (B), U26.12 (D1)
/Memory Controller/ID2: U21.16 (B2), U25.4 (C), U26.13 (D2)
/Memory Controller/ID3: U21.15 (B3), U25.5 (D), U26.15 (D3)
/Memory Controller/ID4: U21.14 (B4), U25.10 (E), U26.16 (D4)
/Memory Controller/ID5: U21.13 (B5), U25.11 (F), U26.17 (D5)
/Memory Controller/ID6: U21.12 (B6), U25.12 (G), U26.18 (D6)
/Memory Controller/ID7: U21.11 (B7), U25.14 (H), U26.19 (D7)
/Memory Controller/~AllowWrite: U9.6 (~Q), U22.2
/Memory Controller/~CPUBUS: U20.5 (Q), U21.19 (CE), U23.19 (CE), U28.19 (CE)
/Memory Controller/~GPUBUS: U2.2, U20.6 (~Q), U20.12 (D), U24.19 (CE), U25.15 (PE), U29.19 (CE)
A0: U23.2 (A0); also elsewhere on the board
A1: U23.3 (A1); also elsewhere on the board
A2: U23.4 (A2); also elsewhere on the board
A3: U23.5 (A3); also elsewhere on the board
A4: U23.6 (A4); also elsewhere on the board
A5: U23.7 (A5); also elsewhere on the board
A6: U23.8 (A6); also elsewhere on the board
A7: U23.9 (A7); also elsewhere on the board
A8: U28.2 (A0); also elsewhere on the board
A9: U28.3 (A1); also elsewhere on the board
A10: U28.4 (A2); also elsewhere on the board
A11: U28.5 (A3); also elsewhere on the board
A12: U28.6 (A4); also elsewhere on the board
A13: U28.7 (A5); also elsewhere on the board
A14: U28.8 (A6); also elsewhere on the board
A15: U28.9 (A7); also elsewhere on the board
CPU_PHI0: U9.9 (Q); also elsewhere on the board
D0: U21.2 (A0); also elsewhere on the board
D1: U21.3 (A1); also elsewhere on the board
D2: U21.4 (A2); also elsewhere on the board
D3: U21.5 (A3); also elsewhere on the board
D4: U21.6 (A4); also elsewhere on the board
D5: U21.7 (A5); also elsewhere on the board
D6: U21.8 (A6); also elsewhere on the board
D7: U21.9 (A7); also elsewhere on the board
GND: R2.2, U21.10 (GND), U23.10 (GND), U24.1 (A->B), U24.10 (GND), U25.8 (GND), U26.14 (GND), U28.10 (GND), U29.1 (A->B), U29.10 (GND); also elsewhere on the board
HOn: U25.9 (Clr); also elsewhere on the board
LUM: U25.13 (Qh); also elsewhere on the board
unnamed: R2.1, U29.11 (B7)
unnamed: U2.3, U26.22 (~OE)
unnamed: U2.6, U9.2 (D)
unnamed: U20.1 (~R), U20.9 (Q)
unnamed: U21.1 (A->B), U22.6
unnamed: U22.3, U26.27 (~WE)
VCC: U9.1 (~R), U9.4 (~S), U9.10 (~S), U9.13 (~R), U20.2 (D), U20.4 (~S), U20.10 (~S), U20.13 (~R), U21.20 (VCC), U23.1 (A->B), U23.20 (VCC), U24.20 (VCC), U25.1 (Ds), U25.16 (VCC), U26.28 (VCC), U28.1 (A->B), U28.20 (VCC), U29.20 (VCC); also elsewhere on the board
VCOL3: U24.18 (B0); also elsewhere on the board
VCOL4: U24.17 (B1); also elsewhere on the board
VCOL5: U24.16 (B2); also elsewhere on the board
VCOL6: U24.15 (B3); also elsewhere on the board
VCOL7: U24.14 (B4); also elsewhere on the board
VCOL8: U24.13 (B5); also elsewhere on the board
VROW0: U24.12 (B6); also elsewhere on the board
VROW1: U24.11 (B7); also elsewhere on the board
VROW2: U29.18 (B0); also elsewhere on the board
VROW3: U29.17 (B1); also elsewhere on the board
VROW4: U29.16 (B2); also elsewhere on the board
VROW5: U29.15 (B3); also elsewhere on the board
VROW6: U29.14 (B4); also elsewhere on the board
VROW7: U29.13 (B5); also elsewhere on the board
VROW8: U29.12 (B6); also elsewhere on the board
~2MHz: U2.5; also elsewhere on the board
~CPU_PHI_R: U2.1, U22.4; also elsewhere on the board
~CPU_PHI_W: U22.1; also elsewhere on the board

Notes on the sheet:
512
312
25.5 is first visible halfrow
0 = 310
4 = 2
25.5 = 23.5
480
288
384x256
Shift register control
CPU control
Read cycle
Write cycle
Clock and dividers
Bus arbitration

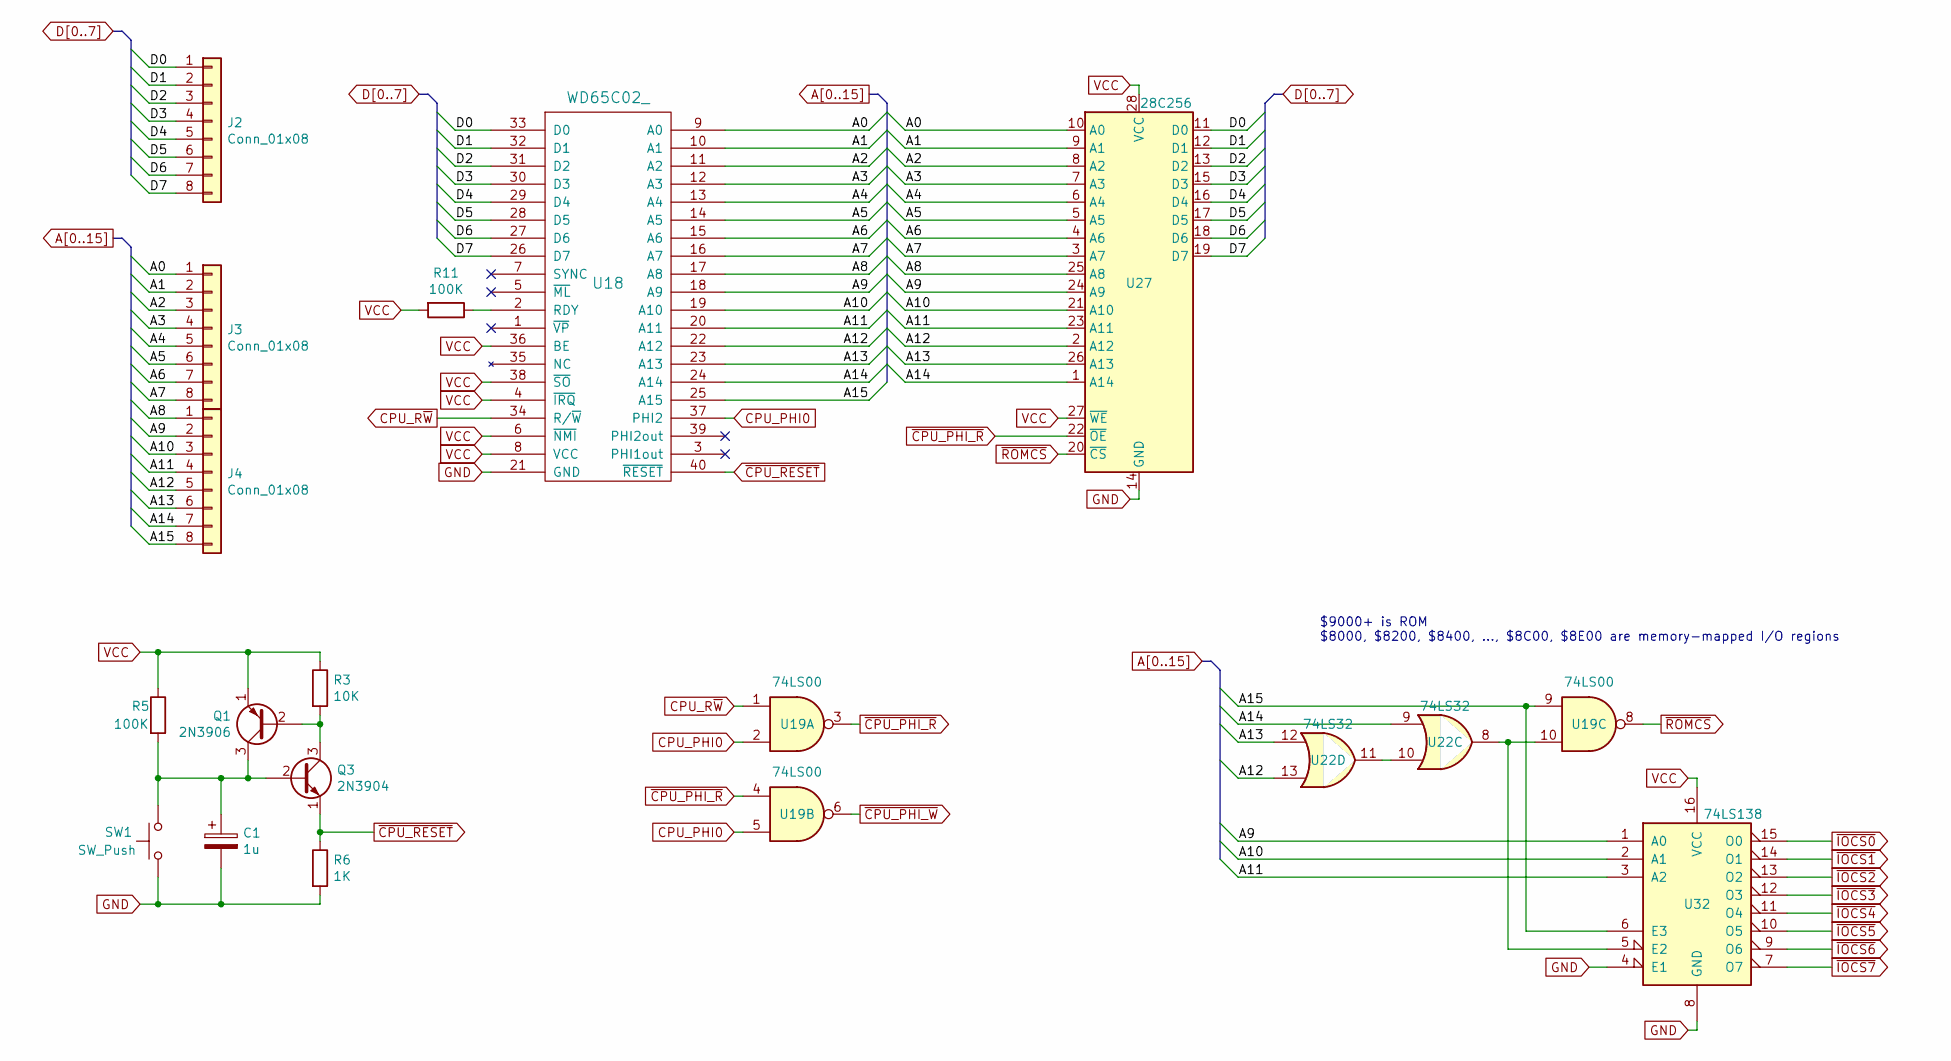
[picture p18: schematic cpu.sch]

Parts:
C1: 1u; CP_Radial_D5.0mm_P2.50mm
J2, J3, J4: Conn_01x08; PinHeader_1x08_P2.54mm_Vertical
Q1: 2N3906; TO-92_Inline
Q3: 2N3904; TO-92_Inline
R3: 10K; R_Axial_DIN0207_L6.3mm_D2.5mm_P7.62mm_Horizontal
R5, R11: 100K; R_Axial_DIN0207_L6.3mm_D2.5mm_P7.62mm_Horizontal
R6: 1K; R_Axial_DIN0207_L6.3mm_D2.5mm_P7.62mm_Horizontal
SW1: SW_Push; SW_PUSH_6mm
U18: WD65C02_; DIP-40_W15.24mm
U19: 74LS00; DIP-14_W7.62mm
U22: 74LS32; DIP-14_W7.62mm
U27: 28C256; DIP-28_W15.24mm
U32: 74LS138; DIP-16_W7.62mm

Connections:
A0: J3.1, U18.9 (A0), U27.10 (A0); also elsewhere on the board
A1: J3.2, U18.10 (A1), U27.9 (A1); also elsewhere on the board
A2: J3.3, U18.11 (A2), U27.8 (A2); also elsewhere on the board
A3: J3.4, U18.12 (A3), U27.7 (A3); also elsewhere on the board
A4: J3.5, U18.13 (A4), U27.6 (A4); also elsewhere on the board
A5: J3.6, U18.14 (A5), U27.5 (A5); also elsewhere on the board
A6: J3.7, U18.15 (A6), U27.4 (A6); also elsewhere on the board
A7: J3.8, U18.16 (A7), U27.3 (A7); also elsewhere on the board
A8: J4.1, U18.17 (A8), U27.25 (A8); also elsewhere on the board
A9: J4.2, U18.18 (A9), U27.24 (A9), U32.1 (A0); also elsewhere on the board
A10: J4.3, U18.19 (A10), U27.21 (A10), U32.2 (A1); also elsewhere on the board
A11: J4.4, U18.20 (A11), U27.23 (A11), U32.3 (A2); also elsewhere on the board
A12: J4.5, U18.22 (A12), U22.13, U27.2 (A12); also elsewhere on the board
A13: J4.6, U18.23 (A13), U22.12, U27.26 (A13); also elsewhere on the board
A14: J4.7, U18.24 (A14), U22.9, U27.1 (A14); also elsewhere on the board
A15: J4.8, U18.25 (A15), U19.9, U32.6 (E3); also elsewhere on the board
CPU_PHI0: U18.37 (PHI2), U19.2, U19.5; also elsewhere on the board
CPU_R~W: U18.34 (R/~W), U19.1
D0: J2.1, U18.33 (D0), U27.11 (D0); also elsewhere on the board
D1: J2.2, U18.32 (D1), U27.12 (D1); also elsewhere on the board
D2: J2.3, U18.31 (D2), U27.13 (D2); also elsewhere on the board
D3: J2.4, U18.30 (D3), U27.15 (D3); also elsewhere on the board
D4: J2.5, U18.29 (D4), U27.16 (D4); also elsewhere on the board
D5: J2.6, U18.28 (D5), U27.17 (D5); also elsewhere on the board
D6: J2.7, U18.27 (D6), U27.18 (D6); also elsewhere on the board
D7: J2.8, U18.26 (D7), U27.19 (D7); also elsewhere on the board
GND: C1.2, R6.2, SW1.1, U18.21 (GND), U27.14 (GND), U32.4 (E1), U32.8 (GND); also elsewhere on the board
unnamed: C1.1, Q1.3 (C), Q3.2 (B), R5.2, SW1.2
unnamed: Q1.2 (B), Q3.3 (C), R3.2
unnamed: R11.1, U18.2 (RDY)
unnamed: U19.10, U22.8, U32.5 (E2)
unnamed: U22.10, U22.11
VCC: Q1.1 (E), R3.1, R5.1, R11.2, U18.4 (~IRQ), U18.6 (~NMI), U18.8 (VCC), U18.36 (BE), U18.38 (~SO), U27.27 (~WE), U27.28 (VCC), U32.16 (VCC); also elsewhere on the board
~CPU_PHI_R: U19.3, U19.4, U27.22 (~OE); also elsewhere on the board
~CPU_PHI_W: U19.6; also elsewhere on the board
~CPU_RESET: Q3.1 (E), R6.1, U18.40 (~RESET)
~IOCS0: U32.15 (O0)
~IOCS1: U32.14 (O1)
~IOCS2: U32.13 (O2)
~IOCS3: U32.12 (O3)
~IOCS4: U32.11 (O4)
~IOCS5: U32.10 (O5)
~IOCS6: U32.9 (O6)
~IOCS7: U32.7 (O7)
~ROMCS: U19.8, U27.20 (~CS)

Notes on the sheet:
$9000+ is ROM $8000, $8200, $8400, ..., $8C00, $8E00 are memory-mapped I/O regions

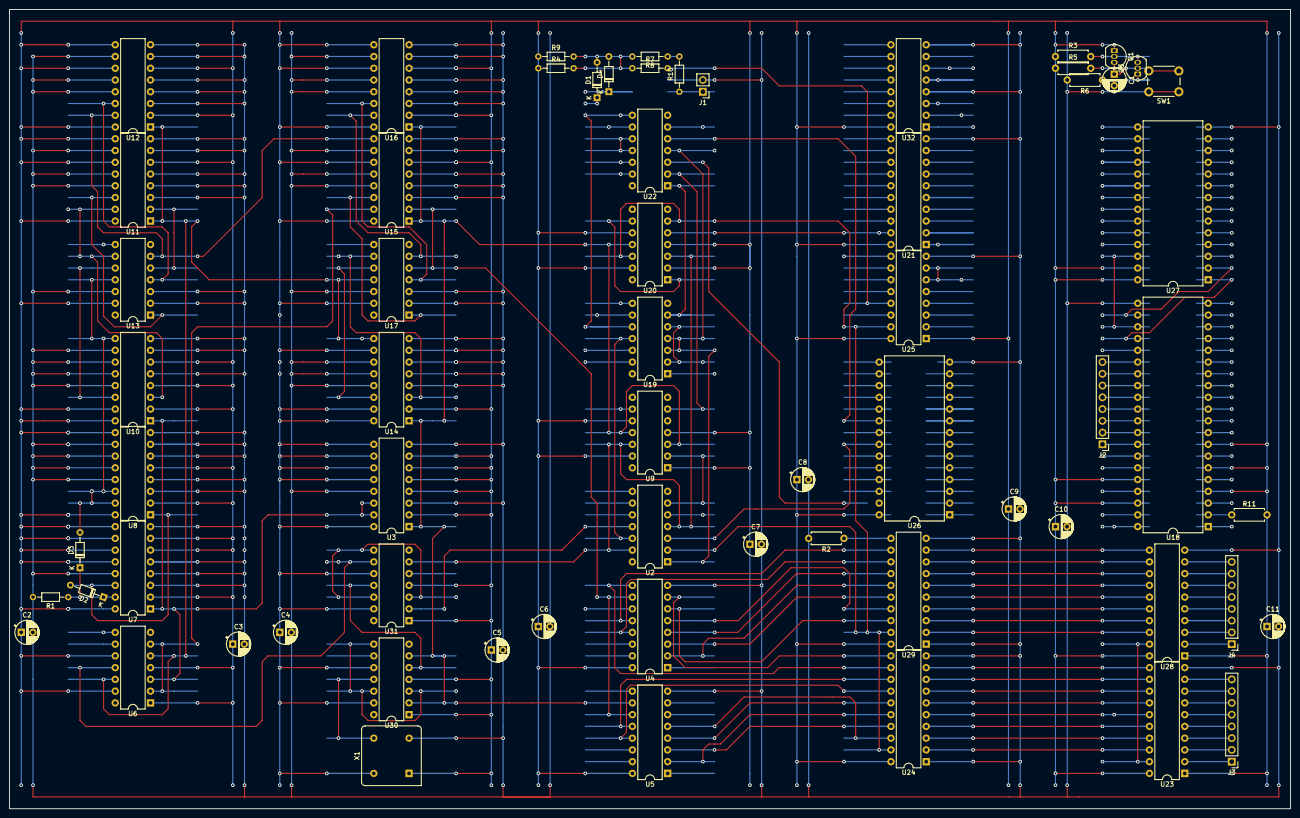
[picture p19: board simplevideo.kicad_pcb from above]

Board: 4 copper layers, 276.9 x 172.7 mm, 65 parts (0 on the bottom side), 118 nets.

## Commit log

2020-06-10 Include 6502, ROM, etc in circuit, all laid out together
    [coordinates.sch, coretiming.sch, cpu.sch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]
2020-06-12 New address decoding scheme and complete breadboard layout, should be ready to build
    [coordinates.sch, coretiming.sch, cpu.sch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]
2020-06-12 Minor edits
    [cpu.sch, memorycontroller.sch, simplevideo.sch]
2020-06-21 Fixed various issues discovered during building and testing
    [coretiming.sch, cpu.sch, htiming.sch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]
2020-09-17 Moved timing diagrams to separate schematic sheet; included PDF of schematics
    [coordinates.sch, coretiming.sch, cpu.sch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]
2020-09-17 Add schematic thumbnail; update README.md
